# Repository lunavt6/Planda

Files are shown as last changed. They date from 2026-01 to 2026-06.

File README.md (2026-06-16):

# Planda
Een interactieve knuffelbeer die kinderen op een speelse en zelfstandige manier helpt bij het aanleren van dagelijkse taakjes.

🛠️ Built by ``Doren Vermaut`` & ``Luna Van Tittelboom`` & ``Bram Eeckhout``    
🔥 Supervised by ``prof. dr. Bas Baccarne``, ``Yannick Christiaens`` & ``Wouter Devriese``    
🌱 Grown at ``Ghent University`` 🏛️ ``Industrial Design Engineering`` ([project overview](https://github.com/basbaccarne/human-centered-design))       

*11/06/2026*   

## Samenvatting
Veel jonge ouders ervaren dagelijks stress tijdens het aanleren van routinetaken aan jonge kinderen. Taken zoals tanden poetsen, handen wassen, naar het toilet gaan of de boekentas voorbereiden vragen vaak voortdurende begeleiding, herhaling en controle. Dit zorgt voor frustratie bij zowel ouder als kind en vermindert de zelfstandigheid van het kind.

Om dit probleem te onderzoeken, doorliepen we een iteratief human-centered designproces met interviews, observaties, storyboards, benchmarking, ergonomische analyses en verschillende testwaves met prototypes. Tijdens het eerste semester lag de focus op een plannings- en routine-instrument voor de ochtendroutine. Uit feedback en gebruikerstesten bleek echter dat een puur planningsgericht systeem minder geschikt was binnen de hectiek van de ochtend. Daarom evolueerde het concept naar een interactieve begeleidende knuffelbeer die kinderen pedagogisch ondersteunt bij het aanleren van dagelijkse taakjes.

De uiteindelijke oplossing bestaat uit een zachte interactieve knuffelbeer met een scherm op de buik waarop visuele stappenplannen worden weergegeven. Via knoppen in de oortjes navigeert het kind doorheen de taakjes, ondersteund door licht- en geluidsfeedback. De beer begeleidt kinderen stap voor stap op een speelse, intuïtieve en zelfstandige manier, waardoor ouders minder voortdurend moeten tussenkomen en opvoedingsstress vermindert.

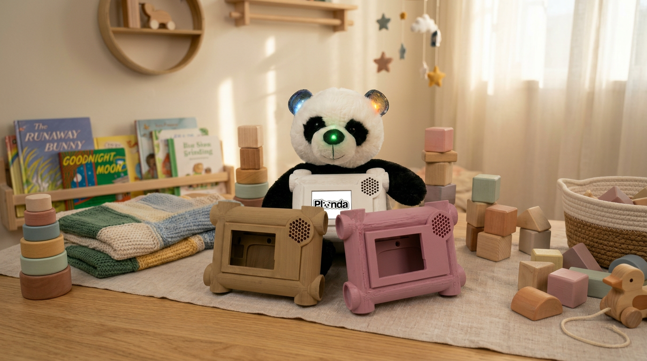
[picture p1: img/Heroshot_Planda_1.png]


## Introductie
Opvoeden brengt niet alleen plezier, maar ook veel stress met zich mee, zeker bij jonge ouders tijdens dagelijkse routines zoals tanden poetsen, handen wassen, aankleden of de boekentas voorbereiden. Veel kinderen hebben moeite om deze taken zelfstandig uit te voeren, waardoor ouders voortdurend moeten begeleiden, herhalen en controleren. Dit zorgt voor tijdsdruk, frustratie en gespannen interacties binnen het gezin.[^1] Onderzoek toont aan dat opvoedingsstress niet alleen een negatieve impact heeft op het welzijn van ouders, maar ook de zelfstandigheid en het zelfvertrouwen van kinderen kan beperken.

Het Planda Beer-project onderzoekt hoe een interactieve knuffelbeer kinderen pedagogisch kan begeleiden bij het aanleren van dagelijkse taakjes. In tegenstelling tot een klassiek planningsinstrument richt het concept zich op het stap voor stap ondersteunen van het kind via een speelse, fysieke en digitale interactie. De beer combineert een scherminterface met auditieve en visuele feedback, zoals geluid, LED-lichtjes en intuïtieve knopinteractie via de oortjes. Op deze manier wordt het kind zelfstandig begeleid zonder dat de ouder voortdurend actief moet tussenkomen.

Om tot deze oplossing te komen, werd een iteratief human-centered designproces doorlopen met interviews, observaties, storyboards, benchmarking, ergonomische analyses en meerdere prototypewaves. Hierbij werd onderzocht hoe kinderen reageren op licht, geluid, symbolen, feedback en fysieke interactie.

De boundary conditions van het project zijn duidelijk: het product moet veilig, zacht, robuust, intuïtief en kindvriendelijk zijn. Daarnaast mag de technologie geen extra stress creëren, maar net rust, autonomie en positieve interactie stimuleren.

## Inhoudstafel

1. [Methodologie](./docs/methodologie.md)
2. [Discovery](./docs/discovery.md)
3. [Definition](./docs/definition.md)
4. [Development 1](./docs/develop_1.md)
5. [Development 2](./docs/develop_2.md)
6. [Development 3](./docs/develop_3.md)
7. [Design Requirements](./docs/design_requirements.md)
8. [Bill of materials](./docs/bom.md)
9. [Conclusie](./docs/conclusie.md)

## Kritische reflectie
Het Planda‑project heeft over twee semesters heen een duidelijke en betekenisvolle evolutie doorgemaakt. Waar SEM1 vooral gericht was op het begrijpen van opvoedstress, kinderroutines en knuffelgedrag, lag de nadruk in SEM2 op het systematisch bouwen, testen en verfijnen van een interactief product dat zowel functioneel als emotioneel aansluit bij de leefwereld van jonge kinderen. Deze iteratieve aanpak heeft geleid tot een solide ontwerp, maar ook tot belangrijke inzichten over de beperkingen en uitdagingen van het project.

In SEM1 werd duidelijk dat een puur planningsgericht systeem onvoldoende aansluit bij de realiteit van gezinnen. De pivot naar een interactieve knuffelbeer was een cruciale stap: het toonde aan dat kinderen vooral reageren op fysieke, speelse en multisensorische prikkels. De Wizard‑of‑Oz‑testen en conceptual waves maakten zichtbaar hoe kinderen spontaan omgaan met licht, geluid en knuffelinteractie, en hoe belangrijk het is dat technologie zich aanpast aan hun natuurlijke gedrag in plaats van omgekeerd.

In SEM2 werd deze basis verder uitgediept. Develop 1 bracht de complexiteit van de functionele architectuur naar voren: het combineren van fysieke knoppen, visuele stappenplannen en auditieve feedback vraagt om een delicate balans tussen eenvoud en duidelijkheid. Develop 2 legde de nadruk op ergonomie en veiligheid. De antropometrische analyses en usabilitytests toonden aan dat kleine vormverschillen in de oortjes grote impact hebben op intuïtiviteit en comfort. Develop 3 richtte zich op UX en CMF, waarbij tactiliteit, materiaalkeuze en lichtdoorlaatbaarheid bepalend bleken voor de emotionele beleving van het product.

Toch blijven er kritische kanttekeningen. De steekproef blijft beperkt, waardoor sommige inzichten (zoals kleurassociaties of voorkeur voor oorknoppen) niet universeel gegarandeerd zijn. Daarnaast blijft de context van testen relatief gecontroleerd; echte ochtendstress is moeilijk te simuleren. Dit betekent dat gedrag dat in testsituaties voorspelbaar lijkt, in een chaotische ochtendroutine anders kan uitpakken.

Ook de vraag naar langdurige motivatie blijft open: blijven kinderen reageren op licht‑ en geluidsfeedback, of treedt gewenning op na enkele weken? Dit is essentieel, omdat het succes van Planda Beer afhangt van duurzame betrokkenheid. Tot slot introduceert het afneembare scherm praktische uitdagingen: hoewel ouders het waarderen, vormt het een extra handeling die in drukke routines snel vergeten kan worden. Dit vraagt om verdere vereenvoudiging of automatisering.

Daarnaast toont het project aan dat elke ontwerpkeuze een spanningsveld creëert: tussen knuffelbaarheid en functionaliteit, tussen autonomie en veiligheid, tussen eenvoud en veelzijdigheid. Het vinden van de juiste balans blijft een voortdurende uitdaging.

Ondanks deze beperkingen heeft het project een sterke methodologische basis gelegd. De combinatie van kwalitatieve observaties, iteratieve prototyping en empirische validatie heeft geleid tot een onderbouwd ontwerp dat rekening houdt met zowel kind als ouder. De kritische reflectie toont vooral dat Planda Beer potentieel heeft, maar dat verdere testen, grotere steekproeven en langdurige evaluaties noodzakelijk zijn om een product te creëren dat écht werkt in diverse gezinsomgevingen.

## Noot inzake het gebruik van AI
In dit project werd AI enkel als ondersteunend hulpmiddel gebruikt. We zetten AI in om enkele eigen schetsen netter te visualiseren, renders te maken, teksten vlotter te formuleren, en tabellen of schema’s overzichtelijk op te maken zodat ze makkelijk in Visual Studio Code konden worden geïmporteerd. Alle concepten, ontwerpen, analyses en beslissingen zijn volledig door het projectteam zelf ontwikkeld; AI werd uitsluitend ingezet voor vormgeving en taalondersteuning.

## Bijlagen
### Discovery
* Benchmarkonderzoek (N=14)
  * [Protocol](https://drive.google.com/file/d/1VPV1awJDa64VDqinm8LVtdigFpOs-lXI/view?usp=sharing)
  * [Rapport](https://drive.google.com/file/d/1ek-WHoF4-XrpG6pTKncxjXwMrDPfr108/view?usp=sharing)
* Interviews (N=3)
  * [Protocol](https://drive.google.com/file/d/1N_GjyhnOHkRdai5fe6EW2gFWemPGeeNa/view?usp=sharing)
  * [Rapport](https://drive.google.com/file/d/19u9PNdlWeaDVB6IC4Rpc8PkJ9rHKdnLq/view?usp=sharing)
    
### Definition
* User testing wave 1 (N=4)
  * [Protocol](https://drive.google.com/file/d/130vRvOUCvCWISH5MEXmbPGNB_Uw2ju9m/view?usp=drive_link)
  * [Rapport](https://drive.google.com/file/d/1wbh-eud349pPwJQK2OwwAVadwWI7WrDZ/view?usp=drive_link)
* User testing wave 2 (N=6)
  * [Protocol](https://drive.google.com/file/d/1jO9U5P_zEwsMB1liQGqoZsyC6XyTrukl/view?usp=drive_link)
  * [Rapport](https://drive.google.com/file/d/1y09vUGmh9ruJW8-vAtFctbpJqeW_Oqac/view?usp=drive_link)

### Development 1
* Literatuuronderzoek (N=11)
  * [Protocol](https://drive.google.com/file/d/1JkM7xMZF1cOWVq1P75I5-xc_WWrdSNv_/view?usp=sharing)
  * [Rapport](https://drive.google.com/file/d/1lqU_Gb7P2KewI6b2YRbHUHMy500uVC_5/view?usp=sharing)
* User testing (N=3)
  * [Protocol](https://drive.google.com/file/d/15MI33pND1JuIGdH_J8u2If2VXpHv9gB-/view?usp=sharing)
  * [Rapport](https://drive.google.com/file/d/1iAICvbYoYDdQVMLRW9RndhLdhfBj4c1h/view?usp=sharing)

### Development 2
* Antropometrie onderzoek
  * [Rapport](https://drive.google.com/file/d/1W2tFgDZaNar4k2NG-botPuARzz3v3zZD/view?usp=sharing)
* User testing (N=1)
  * [Protocol](https://drive.google.com/file/d/18UV0sOgIwRFaU0k2yumadGYeaR9zQ-xK/view?usp=sharing)
  * [Rapport](https://drive.google.com/file/d/10HXQ8sNEB7mYRsCe3yflU_DUqUeTnOM8/view?usp=sharing)

### Development 3
* User testing (N = 3)
  * [Protocol](https://drive.google.com/file/d/1nMEvOunnXXP05v1LXsKzn6qRlS9hDP_Y/view?usp=sharing)
  * [Rapport](https://drive.google.com/file/d/1Gyd1z_1kM8eNMYuMG_D5NSGw8vEMbcCc/view?usp=sharing)
  * [PowerPoint omhulsel](https://drive.google.com/file/d/1jtBIYcoHiLNUWgVYdP9SYzcHUyG76-D9/view?usp=sharing)
  * [PowerPoint oortjes](https://drive.google.com/file/d/1XNqXtDPErmhQJFLdnw9bNmKRSQDc-u7y/view?usp=sharing)

## Licentie  

This repository contains both software and design materials created as part of an industrial design energineering project at Ghent University.

- **Software and code:** [MIT License](./LICENSE-MIT)  
- **Design, documentation, CAD, and media:** [CC BY 4.0 License](./LICENSE)
  
You are free to reuse and build upon this work, both commercially and non-commercially, as long as proper attribution is given to the original authors.

## Bronnen
[^1]: Persoonlijk interview met Sofie, 18 oktober 2025; persoonlijk interview met Ludovic, 19 oktober 2025; persoonlijk interview met Kaat, 19 oktober 2025.

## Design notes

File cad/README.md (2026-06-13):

Voor ons project hebben we de oortjes van de bestaande beer herontworpen zodat ze kunnen functioneren als drukknoppen.

Hiervoor hebben we de oortjes ontworpen in CAD en vervolgens een mal ontwikkeld waarmee de oortjes gerealiseerd konden worden door silicone in de mal te gieten.

Om de oortjes stevig aan de beer te bevestigen, hebben we daarnaast een bevestigingsboog ontworpen. De oortjes worden op deze boog vastgelijmd, waarna de volledige constructie onder de vacht van de beer wordt geplaatst.

**Bevestegingsboog**

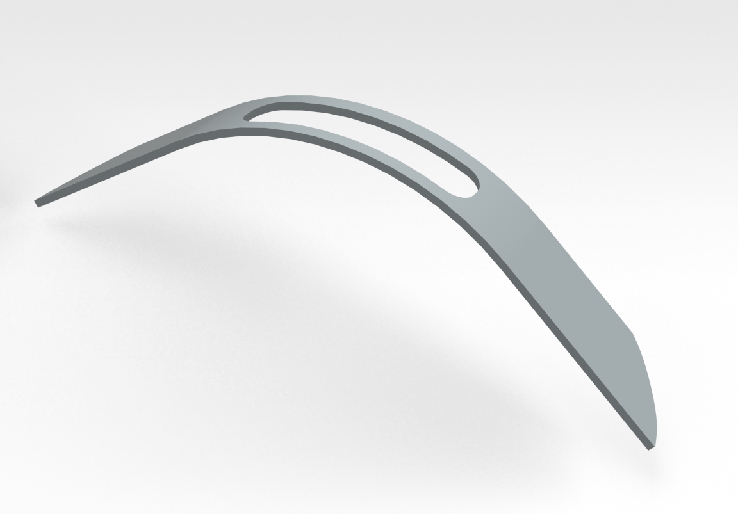
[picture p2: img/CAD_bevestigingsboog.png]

CAD-bestand: [bevestigingsboog.prt](./bevestegingsboog.prt)

**Mal oortje**

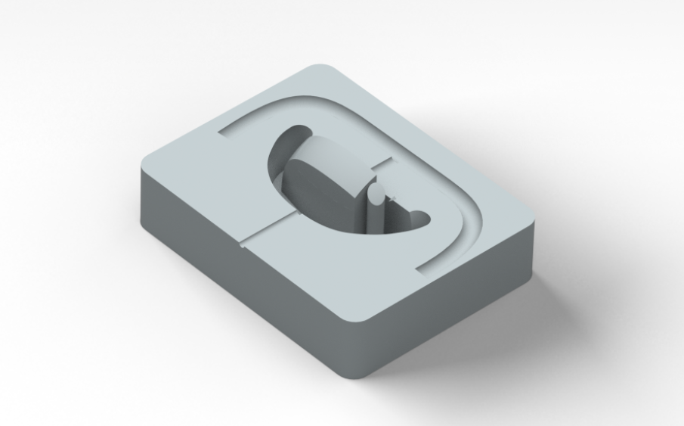
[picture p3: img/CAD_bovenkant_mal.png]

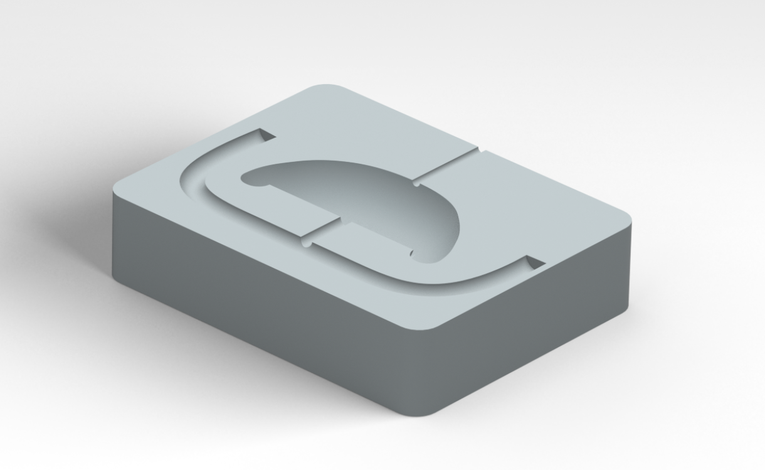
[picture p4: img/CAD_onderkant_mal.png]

CAD-bestand: [mal.prt](./mal.prt)

**Oortje**

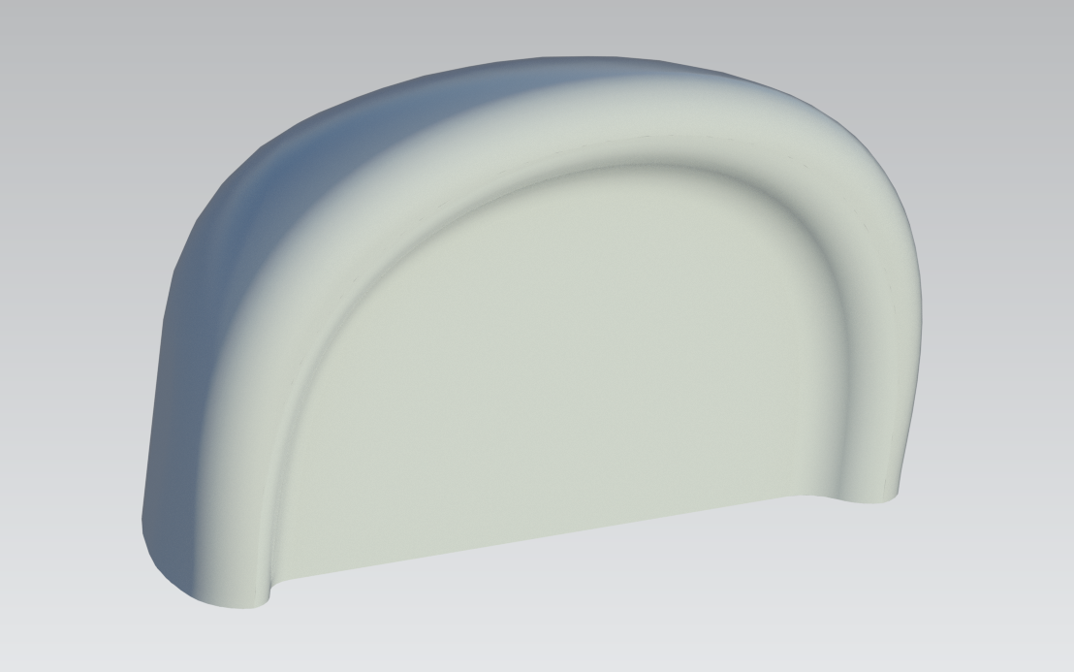
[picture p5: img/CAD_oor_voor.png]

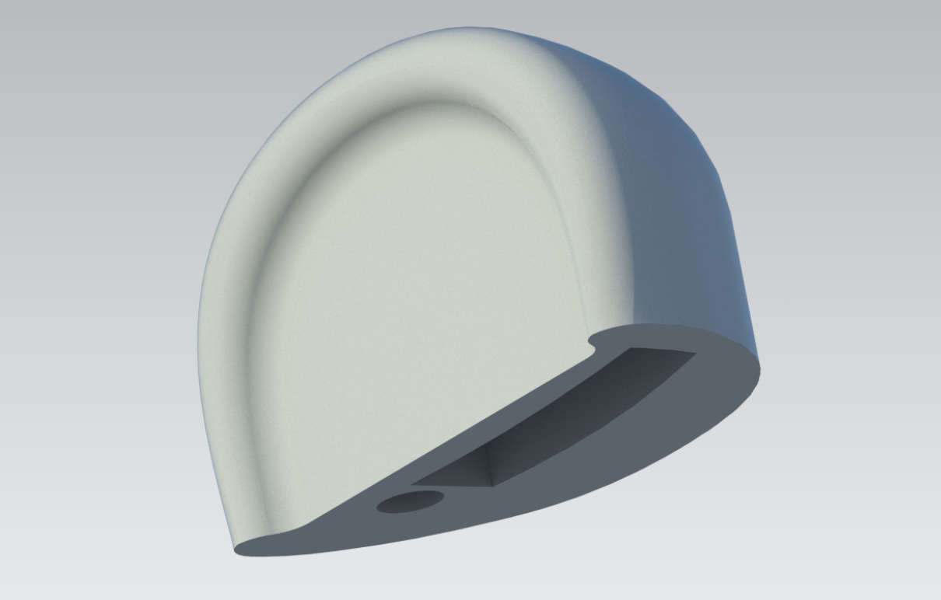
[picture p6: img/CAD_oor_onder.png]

CAD-bestand: [oortjes.prt](./oortjes%20eerste%20versie%20-%20kopie%20-%20kopie.prt)

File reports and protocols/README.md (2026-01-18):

Add PDF versions of your protocols and reports here.   
   
- ❗Make sure this data is pseudonomized (give an alias to your respondent)    
- ❗Don't share personal information here.   
- ❗For informed consents and other documents that contain personal information: Add links to a OndeDrive folder and only give access to teachers.

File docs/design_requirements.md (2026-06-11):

## Overzicht van Design Requirements
|| **Status** || ❌ niet voldaan || ⚠️ gedeeltelijk voldaan || ✅ voldaan || 💭 theoretisch voldaan ||
|ID|Design Requirement|Source|Status|
|:---|:---|:---|:---:|
|**Functionaliteit & Ondersteuning**|
|1.1|Het product geeft taken duidelijk en motiverend weer.|[Discovery](discovery.md)|✅|
|1.2|Het product ondersteunt de gebruiker tijdens de activiteit.|[Discovery](discovery.md)|✅|
|1.3|Het product is personaliseerbaar.|[Discovery](discovery.md)|✅|
|1.4|Het product geeft visuele en auditive feedback aan de gebruiker.|[Definition: Wave 2](definition.md) & [Develop 3](develop_3.md)|✅|
|1.5|Het scherm is losneembaar van het hoofdproduct.|[Definition: Wave 1](definition.md)|✅|
|1.6|De beer biedt aangepaste begeleiding met minstens twee niveaus: een beginnersmodus met gedetailleerde stappen en een gevorderde modus met kortere instructies.|[Develop 1](develop_1.md)|❌|
|1.7|Elke stap communiceert één duidelijke actie en is visueel eenvoudig en herkenbaar voor jonge kinderen.|[Develop 1](develop_1.md)|✅|
|1.8|De beer leest elke stap automatisch voor via een ingebouwde speaker.|[Develop 1](develop_1.md)|❌|
|**Interactie & Bediening**|
|2.1|Het product is intuïtief en eenvoudig te gebruiken.|[Discovery](discovery.md)|✅|
|2.2|Het product beschikt over fysieke knoppen.|[Definition: Wave 1](definition.md)|✅|
|2.3|De knoppen zijn ergonomische en toegankelijke gepositioneerd voor de doelgroep.|[Definition: Wave 1](definition.md)|✅|
|2.4|De knoppen zijn op een logische manier t.o.v. elkaar gepositioneerd. |[Definition: Wave 2](definition.md)|✅|
|2.5|Lichtsignalen geven aan welke knop er moet ingeduwd worden.|[Definition: Wave 2](definition.md)|✅|
|2.6|De kleuren van de lichtsignalen zorgen voor een duidelijke interpretatie.|[Definition: Wave 2](definition.md)|❌|
|2.7|Het product gebruikt geluid om de aandacht van het kind te trekken.|[Definition: Wave 2](definition.md)|✅|
|2.8|Het  oor heeft een grootte die comfortabel en gemakkelijk te gebruiken is voor een kind.|[Develop 2](develop_2.md)|✅|
|2.9|Het oor heeft een voldoende grote contactoppervlak voor een stabiele grip.|[Develop 2](develop_2.md)|✅|
|**Vormgeving & Beleving**|
|3.1|Het product heeft een speels karakter door het gebruik van opvallende kleuren en herkenbare visuele kenmerken.|[Discovery](discovery.md) & [Develop 3](develop_3.md)|✅|
|3.2|Het product behoudt het knuffelaspect.|[Definition: Wave 1](definition.md)|✅|
|3.3|Het product heeft een ergonomische vorm die makkelijk vast te houden is door de doelgroep.|[Definition: Wave 1](definition.md)|✅|
|3.4|Het product bevat onderdelen die gereinigd kunnen worden.|[Definition: Wave 1](definition.md)|💭|
|3.5|De oortjes hebben een zachte en elastische interface.|[Develop 3](develop_3.md)|✅|
|3.6|Het omhulsel voelt glad aan.|[Develop 3](develop_3.md)|✅|
|3.7|Het product is beschikbaar in verschillende kleurvarianten.|[Develop 3](develop_3.md)|❌|
|**Vormgeving app**|
|4.1|De app is eenvoudig en overzichtelijk, zodat ouders snel taken kunnen instellen of aanpassen.|[Develop 1](develop_1.md)|✅|
|4.2|Ouders kunnen routines volledig aanpassen door taken toe te voegen, te verwijderen of de volgorde te wijzigen.|[Develop 1](develop_1.md)|✅|
|4.3|De app bevat standaardtaken.|[Develop 1](develop_1.md)|✅|
|4.4|Ouders kunnen eerder ingestelde routines opslaan en opnieuw gebruiken.|[Develop 1](develop_1.md)|✅|
|4.5|De app ondersteunt meerdere kinderaccounts, zodat elk kind een eigen profiel en voortgang heeft.|[Develop 1](develop_1.md)|✅|
|4.6|Beide ouders kunnen via hun eigen smartphone toegang krijgen tot de beer en voortgang bekijken.|[Develop 1](develop_1.md)|✅|
|4.7|Voortgang van kinderen wordt visueel weergegeven.|[Develop 1](develop_1.md)|✅|
|4.8|De app toont voortgang over langere tijd.|[Develop 1](develop_1.md)|✅|
|4.9|Ouders ontvangen herinneringen om oefenmomenten niet te vergeten.|[Develop 1](develop_1.md)|✅|
|4.10|De app geeft praktische tips voor het oefenen van vaardigheden met het kind.|[Develop 1](develop_1.md)|✅|
|4.11|De verbinding tussen de app en de beer is duidelijk zichtbaar, inclusief correcte overdracht van routines.|[Develop 1](develop_1.md)|✅|

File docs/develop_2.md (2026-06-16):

## Development 2

### Doelstellingen
Het hoofddoel van deze fase is het ergonomisch maken van het product en wordt de opstelling verbeterd.

---

### Ergonomie

#### Materiaal & methoden
Om de beer op ergonomisch vlak te kunnen evalueren, werd hij geanalyseerd op zijn verschillende componenten. Al snel werd duidelijk dat enkel de oren (die dienen als knoppen) een ergonomisch aspect bevatten. Deze knoppen moeten namelijk gemakkelijk inknijpbaar zijn en goed in de hand liggen van kinderen.

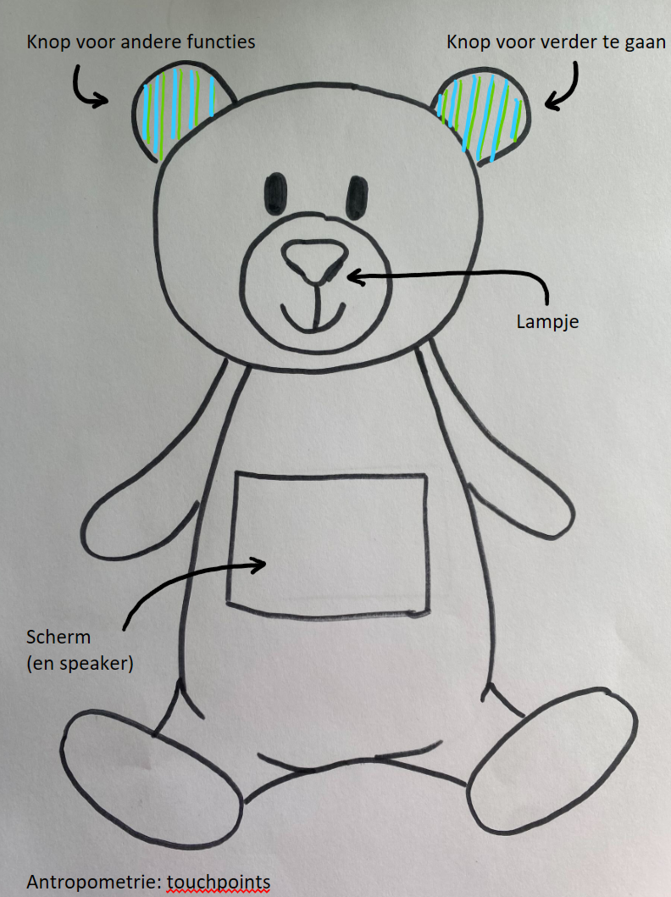
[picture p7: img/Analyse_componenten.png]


Er werd een antropometrische analyse uitgevoerd waarbij onderzocht werd op welke verschillende manieren kinderen kunnen knijpen in een voorwerp en welke krachten zij daarbij uitoefenen. De nodige informatie werd gehaald uit een academisch verslag, gevonden via Google Scholar, aangezien bestaande antropometrische databanken niet veel specifieke gegevens bevatten over kinderhanden. In dit verslag werden verschillende tabellen met krachtwaarden geraadpleegd. Hieruit werden enkel de resultaten voor 5 – 6 jarigen gebruikt, aangezien deze de enige zijn die zich in de doelgroep bevinden. Daarnaast werd het principe van “design for the small” toegepast, zodat het ontwerp ook geschikt blijft voor grotere handen en sterkere krachten.

Deze analyse maakte het duidelijk wat er verder onderzocht moest worden in de gebruikerstesten. Tijdens de testen werd gekeken naar de handzetting van de kinderen op de oren en naar welke oorgrootte zij het meest gebruiksvriendelijk vinden. Het prototype hiervoor is te zien in onderstaande afbeelding.

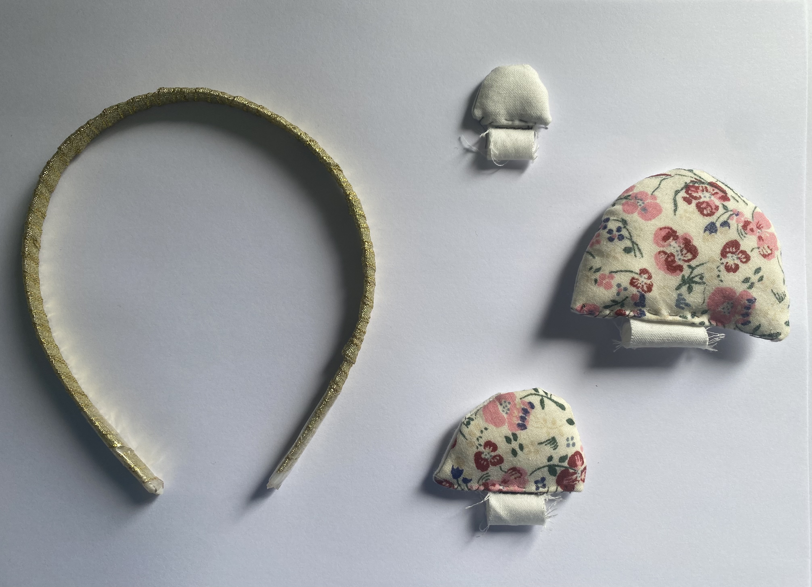
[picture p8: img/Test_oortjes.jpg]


Het protocol van de gebruikerstesten is [hier](https://drive.google.com/file/d/18UV0sOgIwRFaU0k2yumadGYeaR9zQ-xK/view?usp=sharing) te vinden.

#### Resultaten

##### Antropometrisch onderzoek
Uit de antropometrische analyse is gebleken dat er toch een groot verschil is in de uitgeoefende krachten, afhankelijk van de manier van knijpen. Dit wordt weergegeven in onderstaande tabel, waarin telkens de minimale krachtwaarden zijn opgenomen. 

|Soort kracht|Minimum kracht (in N)|Afbeelding|
|---|---|---|
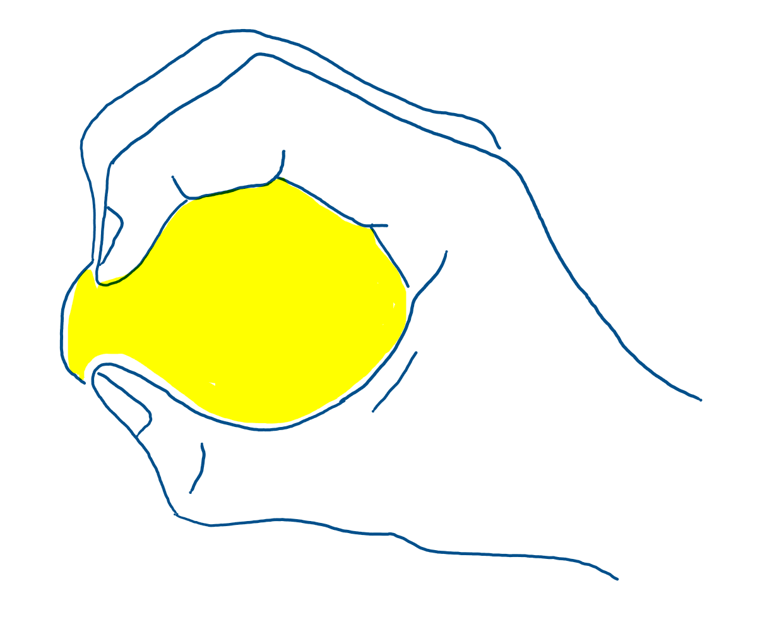
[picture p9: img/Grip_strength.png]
|Grip strength|75.62||
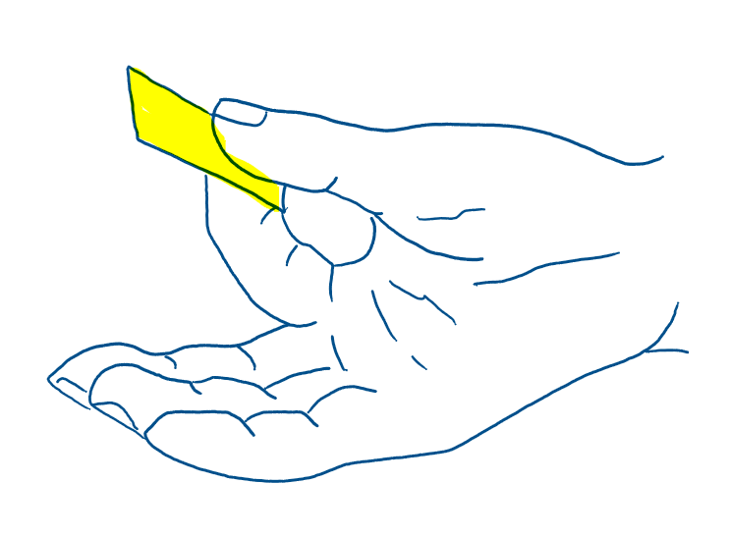
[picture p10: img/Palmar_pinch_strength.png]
|Palmar pinch strength|13.79||
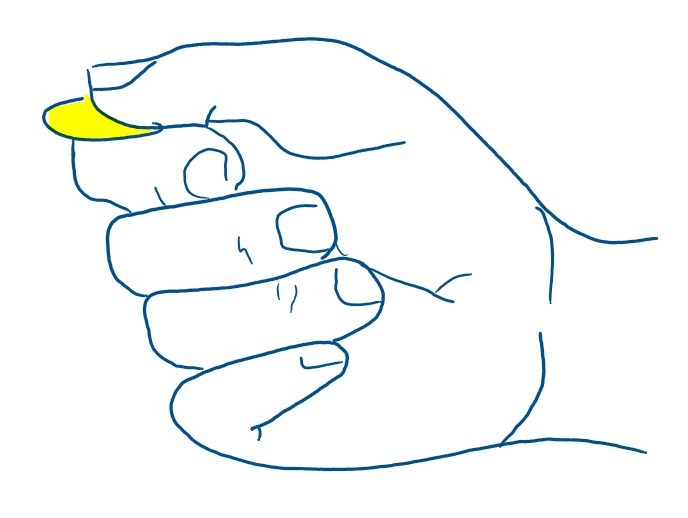
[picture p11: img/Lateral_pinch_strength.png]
|Lateral pinch strength|8.01||

Uit deze tabel blijkt dat het belangrijk is om rekening te houden met de manier waarop kinderen de knoppen bedienen. De kracht die wordt uitgeoefend met de vingers verschilt namelijk sterk van de kracht die met de volledige hand wordt gebruikt. Het is daarom belangrijk om te weten te komen hoe kinderen de knoppen spontaan indrukken. 

Voor het bepalen van de grootte van de knoppen werd er geen bruikbare data gevonden. Daarom worden er verschillende quick-and-dirty prototypes gemaakt met variërende knopgroottes, zodat getest kan worden welke afmetingen het meest comfortabel zijn voor de kinderen.

De analyse van het antropometrisch onderzoek is [hier](https://drive.google.com/file/d/1W2tFgDZaNar4k2NG-botPuARzz3v3zZD/view?usp=sharing) te vinden.

##### Testinterviews
Er wordt gevraagd aan het kind om in de oor van de beer te knijpen zoals te zien is in onderstaande afbeelding en dit wordt dan herhaald voor de verschillende groottes.

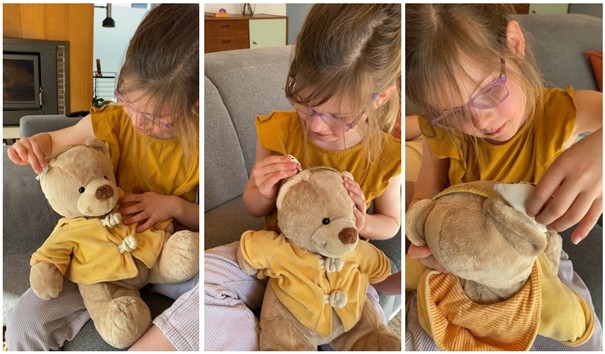
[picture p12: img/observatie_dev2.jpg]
observatie


De positie van de hand werd per oorgrootte vijf keer geobserveerd. Deze observaties worden samengevat in onderstaande tabel.

| | 1 | 2 | 3 | 4 | 5 |
|---|---|---|---|---|---|
| **Kleinste** | Duim + 2 vingers | Duim + 2 vingers | Duim + 2 vingers | Duim + 2 vingers | Duim + 2 vingers |
| **Middelste**  | Duim + 1 vinger  | Duim + 3 vingers | Duim + 2 vingers | Duim + 3 vingers | Volledig hand |
| **Grootste** | Duim + 3 vingers | Duim + zijkant vinger | Duim + 3 vingers | Duim + 3 vingers | Duim + 3 vingers |

Uit de resultaten kan worden afgeleid dat de knop meestal wordt bediend met de duim in combinatie met één of meerdere vingers. Deze manier van vasthouden lijkt de voorkeur te hebben. Daarnaast is er een duidelijk verschil zichtbaar afhankelijk van de grootte van het oor. Bij het kleinste oor wordt hele tijd gebruikgemaakt van de duim samen met twee vingers. Bij het middelste oor varieert de handpositie sterker, van de duim met één vinger tot het gebruik van het volledige hand. Bij het grootste oor wordt voornamelijk de duim samen met drie vingers gebruikt.

Hieruit kan worden afgeleid dat de grootte van het oor invloed heeft op hoe het kindje de knop vastneemt en gebruikt. Grotere oren zorgen ervoor dat er meer vingers worden gebruikt, terwijl kleinere oren leiden tot een beperktere maar meer vaste handpositie.

Tijdens de evaluatie achteraf gaf het kindje aan dat het middelste oor het meest comfortabel en het gemakkelijkst in gebruik was. Dit komt overeen met de grotere variatie in handposities, wat erop kan wijzen dat deze grootte meer flexibiliteit biedt. 

Het report van de gebruikerstesten is [hier](https://drive.google.com/file/d/10HXQ8sNEB7mYRsCe3yflU_DUqUeTnOM8/view?usp=sharing) te vinden.

---

### Feedback
#### Visueel
Het is belangrijk dat het kind duidelijk begrijpt welke taak uitgevoerd moet worden en op welke manier deze uitgevoerd kan worden. Om de taakjes visueel weer te geven, worden GIF-animaties gebruikt die afgespeeld worden op het TFT-display.

Binnen het systeem wordt een onderscheid gemaakt tussen taakjes en hints. De taakjes tonen enkel de actie die uitgevoerd moet worden. Op deze manier krijgt het kind informatie over wat er moet gebeuren, zonder extra uitleg over de uitvoering. De hints leggen daarentegen meer nadruk op hoe de taak uitgevoerd moet worden en tonen daarom een meer gedetailleerde weergave van de actie.

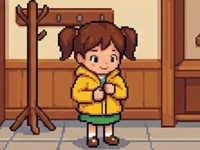
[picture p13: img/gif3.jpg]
    

Omdat de GIF-bestanden momenteel opgeslagen worden in het interne geheugen van de ESP32, is de beschikbare opslagruimte beperkt. Hierdoor moeten de animaties relatief eenvoudig blijven en kunnen ze minder gedetailleerde beelden bevatten. Vooral de GIF-animaties die de uitvoering van een taak uitleggen, zullen hierdoor beperkt zijn in lengte en detail.

Wanneer in een toekomstige versie gebruikgemaakt wordt van de SD-kaartlezer die geïntegreerd is in het TFT-display, kan de opslagcapaciteit aanzienlijk uitgebreid worden. Hierdoor wordt het mogelijk om langere en meer gedetailleerde GIF-animaties te gebruiken.

#### Audio
Naast visuele feedback wordt ook audiofeedback voorzien. Elk taakje wordt eerst door een stem uitgesproken, zodat het kind de opdracht correct begrijpt en de GIF-animatie niet verkeerd interpreteert. Voor de hints wordt eveneens een gesproken uitleg voorzien die beschrijft hoe de taak uitgevoerd moet worden, gevolgd door een ondersteunend muziekje.

Wanneer een taak succesvol voltooid is, krijgt het kind positieve bevestiging via een applausgeluid. Op deze manier wordt de interactie niet enkel informatief, maar ook motiverend gemaakt.

---

### Conclusies & implicaties

#### Ergonomie
Uit het ergonomisch onderzoek en de gebruikerstesten blijkt dat de grootte en vorm van het oor een belangrijke invloed hebben op het gebruiksgemak van de beer. De resultaten geven inzicht in hoe kinderen de oren vastnemen en bedienen, en welke eigenschappen bijdragen aan een comfortabele en betrouwbare interactie.

In onderstaande tabel worden de conclusies weergegeven met de bijhorende reden of onderbouwing waarop de design requirements gebaseerd zijn. 

| Conclusie | Reden |
|---|---|
| Het oor moet een grootte hebben die comfortabel en gemakkelijk te gebruiken is voor kinderen. | Tijdens de gebruikerstesten gaf het kind aan dat het middelste oor het meest comfortabel en het gemakkelijkst in gebruik was. De variatie in handposities wijst erop dat deze grootte voldoende flexibiliteit biedt voor verschillende manieren van vasthouden. |
| Het oor moet een voldoende groot contactoppervlak hebben voor een stabiele grip. | Observaties tonen aan dat kinderen de knop voornamelijk bedienen met de duim en één of meerdere vingers. Een compacter en breder oor biedt een groter contactoppervlak, waardoor kinderen gemakkelijker druk uitoefenen op de juiste plaats en de knop betrouwbaarder activeren. |

> [!IMPORTANT]
> **Design Requirements**
>- 2.8 Het  oor heeft een grootte die comfortabel en gemakkelijk te gebruiken is voor een kind.
>- 2.9 Het oor heeft een voldoende grote contactoppervlak voor een stabiele grip.

#### Aanpassingen oortjes
Tijdens het iteratief ontwerpproces werd de vorm van de oortjes verder verfijnd op basis van de design requirements. Het oorspronkelijke ontwerp bestond uit een langwerpig oortje, maar dit bleek minder geschikt. Enerzijds was deze vorm te lang voor de voorziene mal, en anderzijds zorgde dit voor een minder optimale interactie.

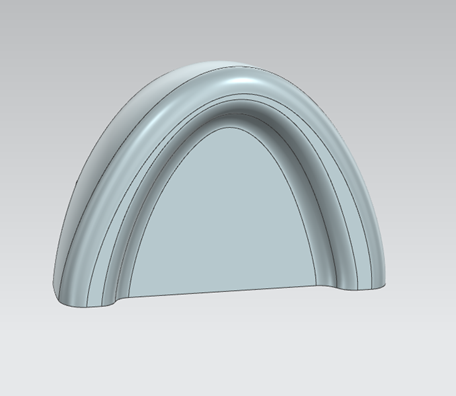
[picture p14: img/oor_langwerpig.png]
langwerpig
 

Een compacter en breder oortje bood een duidelijk betere ergonomische ervaring. Doordat de breedte meer in verhouding staat tot de grootte van de beer, ontstaat er een groter contactoppervlak. Dit verhoogt de kans dat kinderen effectief druk uitoefenen op de juiste plaats en dus succesvol de knop activeren. Bij het langwerpige ontwerp bestond namelijk het risico dat kinderen op de zijkant drukten zonder de interne knop in te drukken. Dit probleem wordt met de huidige vorm vermeden.

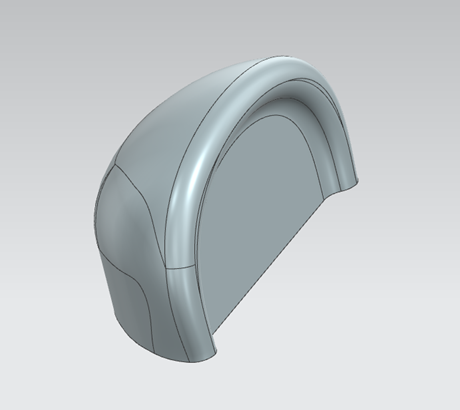
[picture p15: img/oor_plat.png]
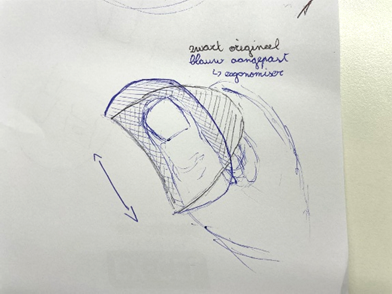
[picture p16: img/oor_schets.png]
 

#### Opstelling
De volgende stappen in het project zijn:
1.	Testen van oren + scherm
2.	Een manier bedenken om het scherm draagbaar te maken door bv. batterijen te gebruiken.

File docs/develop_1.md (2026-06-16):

## Development 1

### Doelstellingen
Het hoofddoel van de eerste develop-fase was het verkennen van de mogelijkheden voor het product, met de volgende deeldoelen: inzicht krijgen in de ontwikkeling van kinderen, onderzoeken hoe zij interageren met de interface van de beer, mogelijke ontwerpen van de bijbehorende app verkennen, en bepalen hoe het product gerealiseerd kan worden.

---

### Materiaal & methoden
Voordat de interviews en literatuuronderzoek konden starten, werd eerst een functionele analyse uitgevoerd. In dit proces werd een verbeterde en meer gedetailleerde versie van het storyboard gemaakt om te onderzoeken wat de verschillende stappen zijn die met en zonder het product doorlopen worden. 

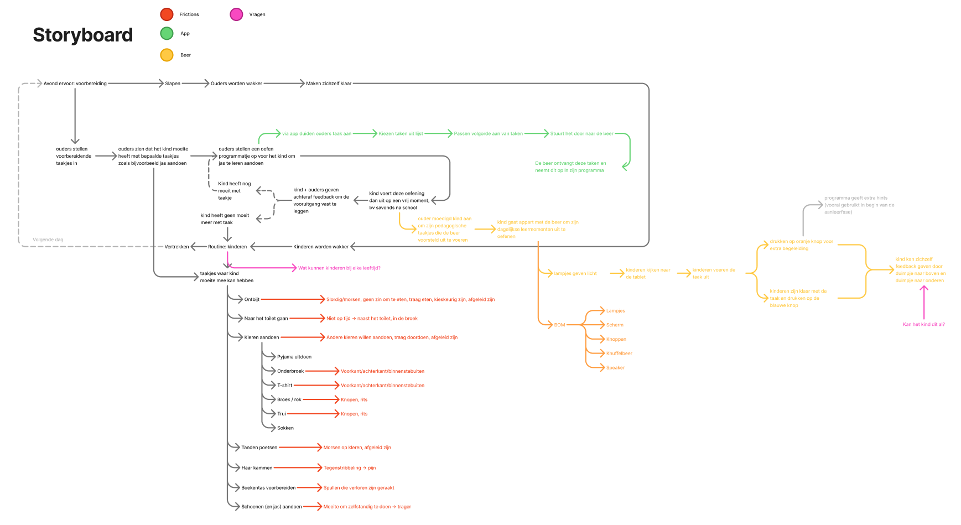
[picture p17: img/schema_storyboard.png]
schema


In onderstaand storyboard wordt er een ideale ochtendroutine voorgesteld.

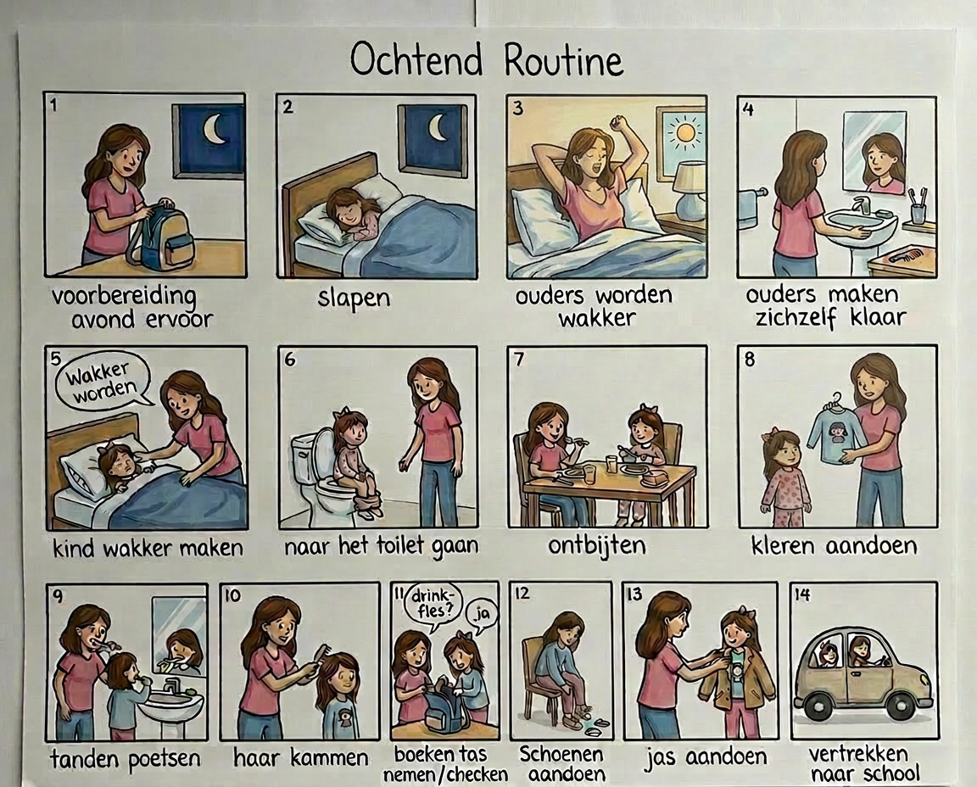
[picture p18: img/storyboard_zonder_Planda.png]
storyboard_zonder_Planda


Aangezien de ochtend niet altijd soepel verloopt, wordt hier ook een worst-case variant van gemaakt.

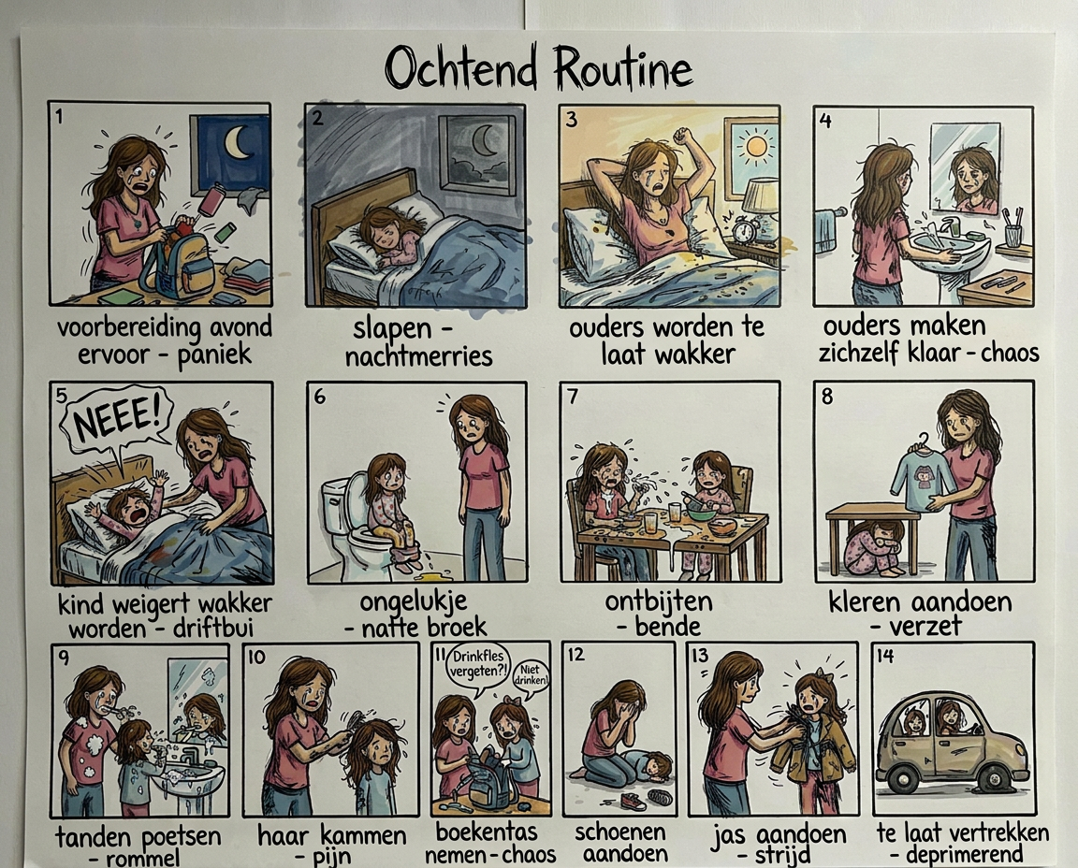
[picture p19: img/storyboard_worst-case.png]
storyboard_worst-case


In onderstaand storyboard is dan te zien waar Planda kan worden ingezet.

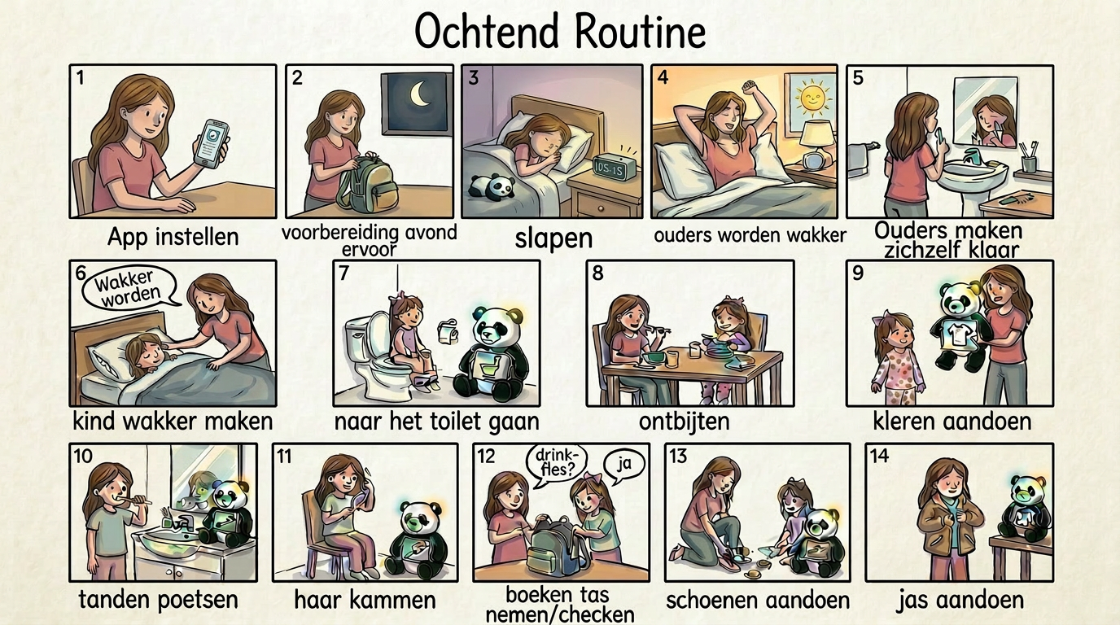
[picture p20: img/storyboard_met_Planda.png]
storyboard_met_Planda


Daarna werd er een literatuuronderzoek uitgevoerd om de ontwikkeling van een kind beter te begrijpen. Hierbij werd onderzoek gedaan naar de verschillende domeinen : motorisch, cognitief, sociaal-emotioneel en taalontwikkeling. Informatie kwam uit openbare bronnen, zoals websites, blogs en academisch onderzoek. Vervolgens werd de informatie vergeleken, zodanig dat er een tijdlijn van kon gemaakt worden. 

Het protocol voor het literatuuronderzoek is [hier](https://drive.google.com/file/d/1JkM7xMZF1cOWVq1P75I5-xc_WWrdSNv_/view?usp=sharing) te vinden.

Tijdens de testen van de interactieve beer werd een Wizard of Oz-opstelling gebruikt. Hierbij fungeerde een fysieke knuffelbeer als tastbare interface, terwijl een smartphone op de buik het Figma-prototype toonde. Via een Bluetooth-muis werden de schermen op afstand bestuurd, zodat de volledige interactiestroom getest kon worden zonder dat de echte hardware en software al ontwikkeld waren. De focus van de test lag vooral op het gedrag, begrip en de motivatie van kinderen tijdens dagelijkse zelfzorgtaken zoals handen wassen.

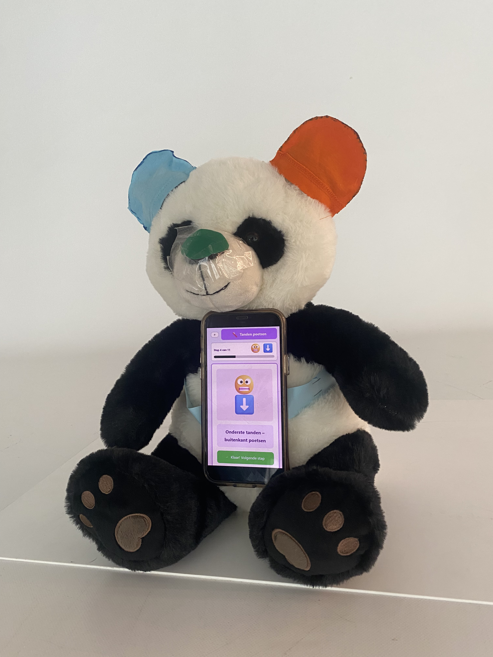
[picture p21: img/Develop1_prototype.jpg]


Daarna werden de noden voor de app onderzocht. Eerst werd aan de geïnterviewden gevraagd wat zij van de app verwachtten. Vervolgens werd een eerste versie van de app getoond en werd gevraagd welke functies of aanpassingen volgens hen nog ontbraken. 

De eerste versie van de app is hier te vinden: [Planda App](https://www.figma.com/make/4M9PoDPEkh4jKd4S3BSqR9/Planda-App-V1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)

Het protocol voor de interview-testen is [hier](https://drive.google.com/file/d/15MI33pND1JuIGdH_J8u2If2VXpHv9gB-/view?usp=sharing) te vinden.

---

### Resultaten
#### Literatuuronderzoek 
Uit dit onderzoek wordt duidelijk waarom gekozen werd voor de doelgroep van 2 tot 6 jaar. In deze periode maken kinderen een sterke ontwikkeling door. Ze zijn nieuwsgierig naar de wereld om zich heen, leren steeds zelfstandiger te worden en bouwen hun sociale vaardigheden verder uit. Tegelijk zetten ze hun eerste stappen in het kleuteronderwijs. Omdat in deze jaren de basis wordt gelegd voor hun verdere ontwikkeling, is het belangrijk om deze leeftijdsgroep goed in kaart te brengen.

Bijgevolg zijn volgende tijdlijnen ontstaan waarbij telkens één domein wordt bekeken.
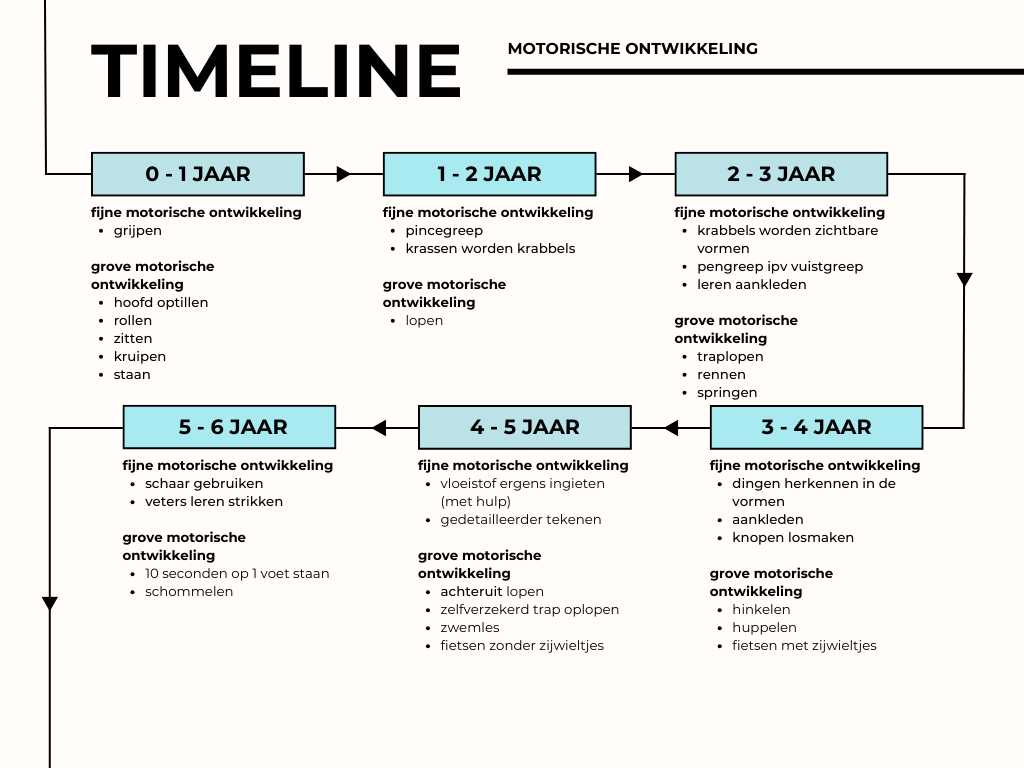
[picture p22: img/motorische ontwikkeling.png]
Motorische

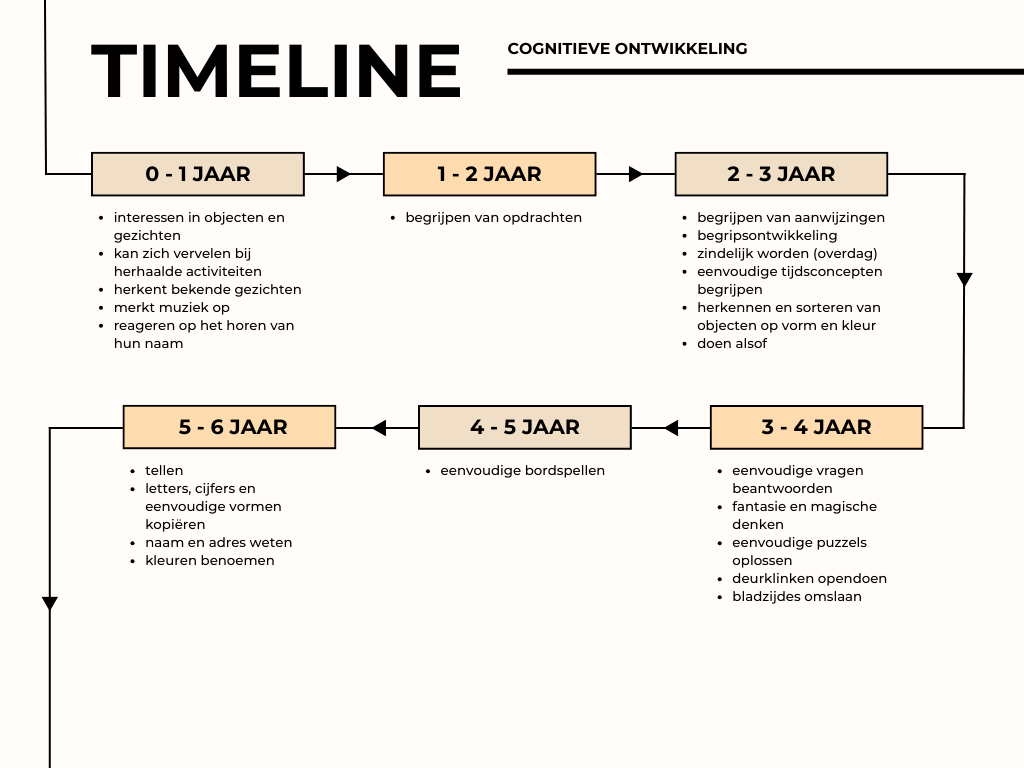
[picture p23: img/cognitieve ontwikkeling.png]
Cognitieve

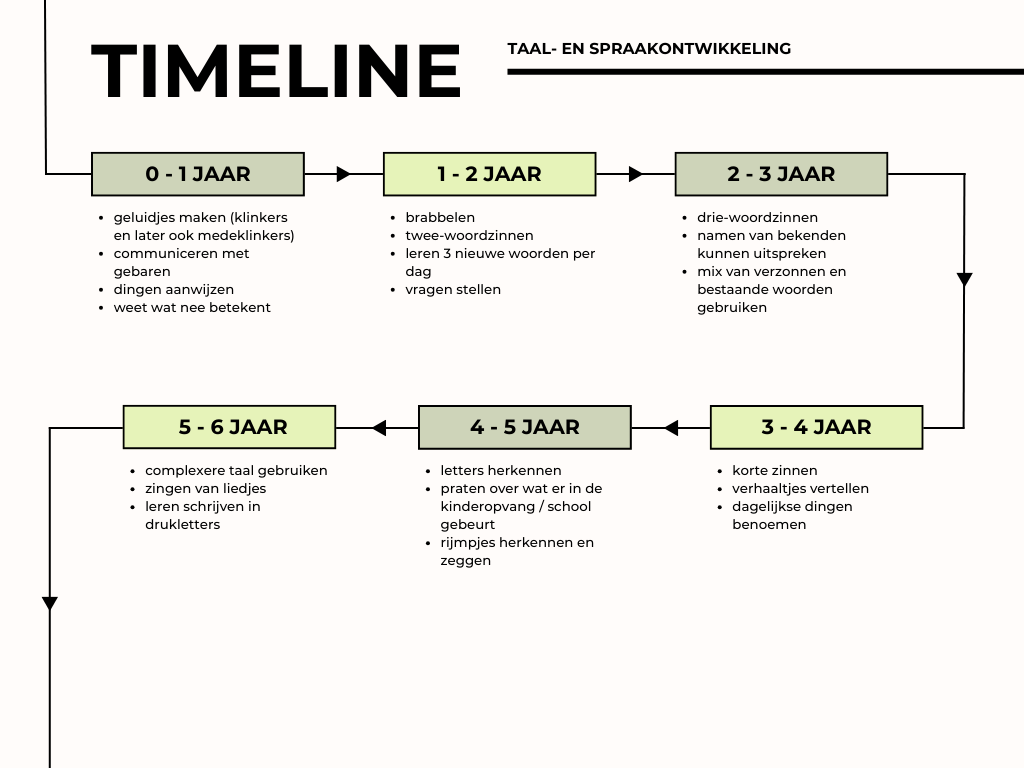
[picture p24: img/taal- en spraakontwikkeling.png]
Taal

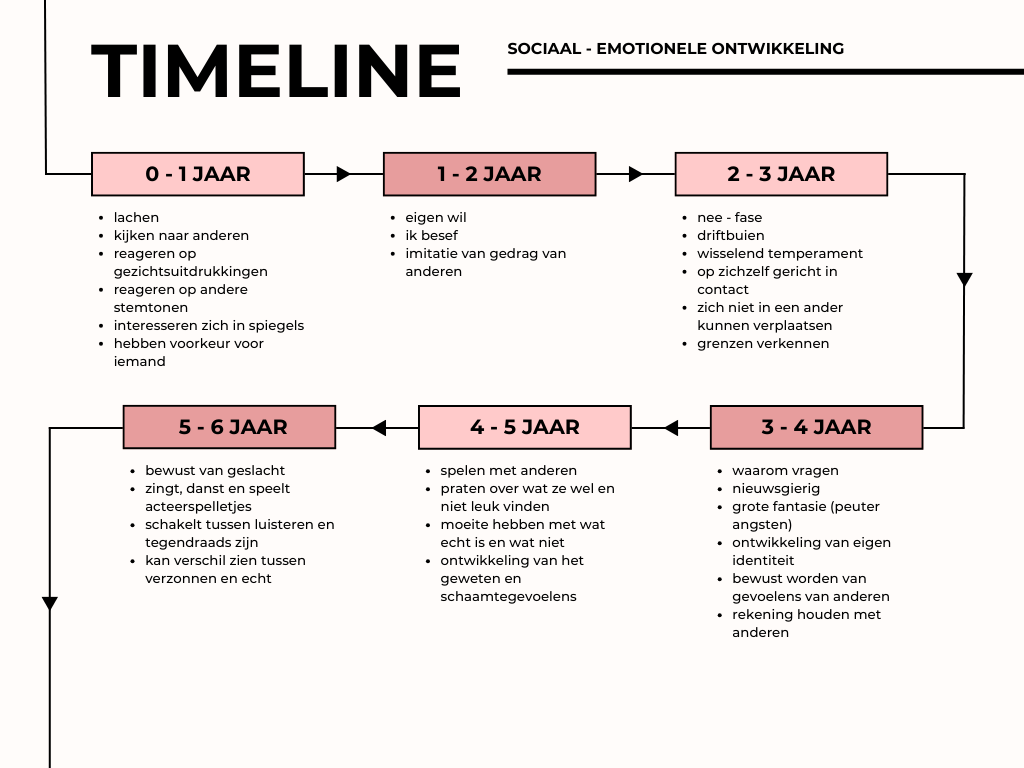
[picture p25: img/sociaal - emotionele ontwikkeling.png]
Sociaal - emotionele


Het report van het literatuuronderzoek is [hier](https://drive.google.com/file/d/1lqU_Gb7P2KewI6b2YRbHUHMy500uVC_5/view?usp=sharing) te vinden.

#### Testinterviews
**Analyse van gebruikerstesten met de interactieve beer**

Uit de testen kwamen verschillende belangrijke inzichten naar voren. Zo bleek dat kinderen verschillende niveaus van begeleiding nodig hebben. Beginners hebben nood aan een gedetailleerd stappenplan met kleine, duidelijke stappen, terwijl kinderen met meer ervaring sneller willen werken. Het systeem moet daarom adaptief zijn en begeleiding kunnen aanpassen aan het niveau van het kind. Daarnaast werd duidelijk dat de interactie soms plaatsvindt in een natte omgeving, waardoor het moeilijk kan zijn om knoppen te bedienen. Daarom is het belangrijk dat de interface waterbestendig en makkelijk schoon te maken is.

Verder bleek dat duidelijke en concrete instructies belangrijk zijn. Te complexe pictogrammen of te veel visuele elementen kunnen verwarrend zijn voor jonge kinderen. Tot slot toonde de test aan dat audiofeedback een grote meerwaarde heeft. Wanneer instructies werden voorgelezen, reageerden kinderen sneller en met meer zekerheid. Audio is daarom essentieel, zeker omdat kinderen in deze leeftijdsgroep vaak nog niet kunnen lezen. Positieve geluidjes en bevestigingen kunnen daarnaast helpen om kinderen gemotiveerd en betrokken te houden. 

**Analyse van de app-interface**

Uit de evaluatie blijkt dat ouders vooral belang hechten aan een eenvoudige, duidelijke en overzichtelijke app. De app moet snel en intuïtief werken, zodat ouders gemakkelijk taken kunnen instellen of aanpassen zonder door complexe menu’s te moeten navigeren. Daarnaast vinden ouders het belangrijk dat routines flexibel aangepast kunnen worden. Vooraf ingestelde taken zoals kleren aandoen, handen wassen of naar het toilet gaan zijn handig, maar ouders willen ook zelf taken kunnen toevoegen en de volgorde ervan aanpassen. Het is bovendien nuttig dat routines opgeslagen kunnen worden, zodat ze later snel opnieuw gebruikt kunnen worden.

Voor gezinnen met meerdere kinderen is het belangrijk dat meerdere accounts mogelijk zijn, zodat de gegevens en voortgang per kind overzichtelijk blijven. Ook moet de app toegankelijk zijn op meerdere smartphones, zodat beide ouders de verbinding met de knuffelbeer kunnen maken en de vooruitgang kunnen opvolgen. Ouders willen daarnaast de voortgang van hun kind kunnen volgen, bijvoorbeeld via visuele feedback zoals sterretjes, badges of een voortgangsbalk, en via een overzicht op langere termijn.

Verder kan het motiverend zijn wanneer kinderen zelf betrokken worden, bijvoorbeeld door de volgorde van taken te kiezen of hun voortgang op de beer te zien. Ook meldingen en tips worden als nuttig beschouwd, omdat ze ouders helpen om oefenmomenten niet te vergeten en ondersteuning bieden bij het oefenen. Tot slot moet de app duidelijk tonen of de knuffelbeer correct verbonden is en of de ingestelde routine goed is doorgestuurd, zodat ouders zeker zijn dat het systeem correct werkt.

Het report van de testinterviews is [hier](https://drive.google.com/file/d/1iAICvbYoYDdQVMLRW9RndhLdhfBj4c1h/view?usp=sharing) te vinden.

---

### Hardware en opstelling
Onderstaand schema geeft de uiteindelijke hardware-opstelling weer die gebruikt zal worden voor de realisatie van dit project. Op basis van deze opstelling werden de nodige componenten geselecteerd en aangekocht. In de volgende fase wordt de hardware opgebouwd en wordt de software ontwikkeld om het volledige systeem te testen.

Opstelling Planda

Binnen dit project worden de taakjes en bijhorende hints opgeslagen in het interne geheugen van de ESP32. Hierdoor blijft het aantal beschikbare taakjes voorlopig beperkt door de opslagcapaciteit van de microcontroller. Het gebruikte TFT-display beschikt echter over een ingebouwde SD-kaartinterface. In een toekomstige uitbreiding kan deze opslagmogelijkheid gebruikt worden om de taakjes en hints extern op te slaan, waardoor een groter aantal taakjes mogelijk wordt.

In de huidige opstelling wordt een pogo-pin connector gebruikt om de verbinding tussen de ESP32 en de componenten in de beer tot stand te brengen. Dankzij de sterke magneten in deze connector kan de aansluiting niet verkeerd gepositioneerd worden, waardoor het omwisselen van de polariteit wordt voorkomen. Daarnaast maakt de magnetische verbinding het mogelijk om de aansluiting snel te koppelen en los te maken.

Omdat het solderen van dergelijke verbindingen extra nauwkeurigheid vereist en mijn ervaring hierin beperkt is, wordt in deze projectfase een eenvoudige zelfgemaakte connector gebruikt op basis van Dupont-kabels. Deze oplossing maakt het mogelijk om de hardware flexibel aan te sluiten en eenvoudig aanpassingen uit te voeren tijdens het ontwikkelproces.

---

### Conclusies & implicaties
Uit de testen blijkt dat het concept goed werkt, maar dat enkele onderdelen nog verder verbeterd moeten worden. Zo is adaptieve begeleiding nodig afhankelijk van het niveau van het kind, zijn waterbestendige knoppen belangrijk in natte situaties en speelt audio een grote rol omdat jonge kinderen vaak nog niet kunnen lezen. 

Daarnaast blijkt dat ouders een eenvoudige en overzichtelijke app willen. Ze willen routines makkelijk kunnen instellen en aanpassen en de voortgang van hun kind kunnen volgen via visuele feedback. 

In onderstaande tabel worden de conclusies weergegeven met de bijhorende reden of onderbouwing waarop de design requirements gebaseerd zijn.

| Conclusie | Reden |
|---|---|
| Het systeem moet minimaal twee begeleidingsniveaus hebben en zich aanpassen aan het kind | Beginners hebben nood aan stap-voor-stap begeleiding, terwijl gevorderde kinderen sneller willen werken |
| Elke stap moet visueel eenvoudig en beperkt tot één actie zijn | Kinderen raken verward door complexe pictogrammen en te veel visuele elementen |
| Audio-instructies zijn essentieel en moeten standaard geïntegreerd zijn | Kinderen reageren sneller en zekerder wanneer stappen worden voorgelezen; velen kunnen nog niet lezen |
| De app moet minimalistisch en intuïtief zijn | Ouders willen snel taken kunnen instellen zonder complexe menu’s |
| Routines moeten volledig bewerkbaar zijn (toevoegen, verwijderen, volgorde wijzigen) | Ouders willen flexibiliteit in het aanpassen van dagelijkse routines |
| De app moet vooraf ingestelde standaardtaken bevatten | Ouders vinden het handig om snel te starten met basisactiviteiten zoals handen wassen en aankleden |
| Gebruikers moeten routines kunnen opslaan en hergebruiken | Dit verhoogt gebruiksgemak en voorkomt telkens opnieuw instellen |
| Ondersteuning voor meerdere kinderprofielen is noodzakelijk | Ouders willen voortgang per kind afzonderlijk kunnen opvolgen |
| De app moet toegang bieden tot beide ouders | Beide ouders willen verbinding kunnen maken en de voortgang kunnen volgen |
| Voortgang moet visueel worden weergegeven | Ouders hebben nood aan een duidelijke en overzichtelijke manier om de voortgang van hun kind snel te kunnen interpreteren via visuele elementen zoals sterretjes, badges en progress bars |
| De app moet voortgang over langere termijn tonen | Ouders willen ontwikkeling en vooruitgang over tijd kunnen opvolgen |
| De app moet herinneringen sturen voor oefenmomenten | Ouders kunnen oefenmomenten anders vergeten |
| De app moet praktische tips geven voor ouders | Ouders hebben behoefte aan ondersteuning bij het begeleiden van hun kind |
| De verbinding tussen app en beer moet duidelijk en zichtbaar zijn | Ouders willen zekerheid dat de routine correct is doorgestuurd en het systeem werkt |

> [!IMPORTANT]
> **Design Requirements**
> - 1.6 De beer biedt aangepaste begeleiding met minstens twee niveaus: een beginnersmodus met gedetailleerde stappen en een gevorderde modus met kortere instructies.
> - 1.7 Elke stap communiceert één duidelijke actie en is visueel eenvoudig en herkenbaar voor jonge kinderen.
> - 1.8 De beer leest elke stap automatisch voor via een ingebouwde speaker.
> - 4.1 De app is eenvoudig en overzichtelijk, zodat ouders snel taken kunnen instellen of aanpassen.
> - 4.2 Ouders kunnen routines volledig aanpassen door taken toe te voegen, te verwijderen of de volgorde te wijzigen.
> - 4.3 De app bevat standaardtaken.
> - 4.4 Ouders kunnen eerder ingestelde routines opslaan en opnieuw gebruiken.
> - 4.5 De app ondersteunt meerdere kinderaccounts, zodat elk kind een eigen profiel en voortgang heeft.
> - 4.6 Beide ouders kunnen via hun eigen smartphone toegang krijgen tot de beer en voortgang bekijken.
> - 4.7 Voortgang van kinderen wordt visueel weergegeven.
> - 4.8 De app toont voortgang over langere tijd.
> - 4.9 Ouders ontvangen herinneringen om oefenmomenten niet te vergeten.
> - 4.10 De app geeft praktische tips voor het oefenen van vaardigheden met het kind.
> - 4.11 De verbinding tussen de app en de beer is duidelijk zichtbaar, inclusief correcte overdracht van routines.

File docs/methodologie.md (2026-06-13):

## Methodologie

triple diamond

Het ontwikkelingsproces van Planda Beer volgde een iteratieve, gebruiksgerichte aanpak, gebaseerd op een aangepast Triple Diamond‑model. In SEM1 lag de nadruk op de discover‑ en definitiefase, waarin we de context van opvoedstress, kinderroutines en motivatie onderzochten. Deze inzichten vormden de basis voor de eerste conceptuele richting van Planda Beer.

### Discovery‑fase (SEM1)
In de discovery‑fase werd de probleemruimte rond ochtend‑ en avondroutines breed verkend. Via user interviews (N=3) met ouders en zorgverleners werden knelpunten, motivaties en strategieën in kaart gebracht. Een benchmarkingstudie (N=14) onderzocht bestaande hulpmiddelen, van educatieve apps tot fysieke routine‑tools, om marktgaten en inspiratiebronnen te identificeren.

Daarnaast werden doelgroep, context en eerste conceptideeën verkend via schetsen en vroege scenario’s. De inzichten werden samengebracht in een persona en een overzicht van noden, frustraties en kansen. Deze fase toonde vooral de nood aan een speels, fysiek én laagdrempelig hulpmiddel dat kinderen ondersteunt zonder extra stress of schermtijd.

### Definitiefase (SEM1)
In de definitiefase werd de probleemdefinitie aangescherpt en vertaald naar concrete conceptrichtingen. Een storyboard visualiseerde hoe Planda Beer een rol kan spelen in dagelijkse routines.

Vroege fysieke en visuele prototypes, van schetsmodellen tot mock-ups, werden getest in meerdere feedbackrondes (N=3). In Wave 1 werden drie conceptuele prototypes onderzocht: een beer met een scherm, een beer met fysieke voorwerpen en een beer met een oplichtend T-shirt. Het prototype met scherm kreeg de voorkeur en werd verder uitgewerkt. Parallel werd de eerste app‑interface ontwikkeld voor ouderlijke configuratie. In Wave 2 werd het geselecteerde schermprototype verder verfijnd. Hierbij werden de signalen (licht en geluid), kleurassociaties en de plaatsing van interactie-elementen geëvalueerd. Op basis van de feedback werd gekozen voor een combinatie van licht en geluid, werden kleuren afgestemd op de emotieherkenning van kinderen en werd de interactie aangepast aan hun intuïtieve links-rechtsassociaties.

#### Inzichten uit Wave 1
- Oren zijn de meest intuïtieve locatie voor knoppen.

- Interactieve elementen mogen de knuffelervaring niet verstoren.

- Licht + korte geluidjes trekken effectief aandacht.

- Geel werkt goed als startkleur; lichtgroen als voltooiingskleur.

#### Wave 2 – Verdere verdieping
- Interactie mag niet op knuffelzones (nek, armen, romp).

- Kinderen koppelen rechts aan “verder” en links aan “terug”.

- Knoppen moeten zacht, vervormbaar en veilig zijn.

Deze inzichten vormden de basis voor SEM2.

### Develop 1 (SEM2)
In deze fase werd het concept functioneel ontleed. Via storyboards, I/O‑architectuur, user flows en een morfologische matrix onderzochten we mogelijke oplossingsrichtingen. Variety prototyping en testen valideerden hypotheses rond navigatie, feedback en taakopbouw.

### Develop 2 (SEM2)
De focus verschoof naar usability en ergonomie. We voerden een antropometrische analyse uit voor de oortjes en bouwden meerdere fysieke varianten. Usabilitytests bevestigden welke vorm, drukweerstand en interactie het meest intuïtief waren.

### Develop 3 (SEM2)
Tot slot werd het product verfijnd op vlak van UX, CMF en emotionele beleving. Via CMF‑analyses, benchmarking en prototypevarianten onderzochten we tactiliteit, kleurpsychologie en lichtdoorlaatbaarheid van de oortjes. Een laatste testwave (N=3) valideerde de finale ontwerpkeuzes. Ook werd er via [vizcom](https://app.vizcom.com/workbench/ae31f0d2-f4ac-4227-a162-1b8fc1ff2d59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) naar verschillende soorten materiaal gezocht.

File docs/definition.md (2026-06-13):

## Definition

### Doelstellingen
Het hoofddoel van dit project is het ontwikkelen van een slim hulpmiddel dat de ochtendroutine voor gezinnen met jonge kinderen (2-6 jaar) verlicht. Het ontwerpproces is opgedeeld in verschillende waves om iteratief te testen en te verbeteren.

> **Wave 1**
>
>Inzicht krijgen in de huidige routines van gezinnen en eerste feedback verzamelen op low-fidelity prototypes en storyboards. De focus lag hierbij op hoe kinderen hun knuffel gebruiken en hoe ontwerpkeuzes de interactie beïnvloeden.

> **Wave 2**
>
> Het optimaliseren van de fysieke materialen en de interactievormen. Specifiek werd onderzocht hoe impulsen (licht/geluid) en beloningen de motivatie van het kind beïnvloeden en welke kleuren/materialen het gebruiksgemak verhogen.

---

### Materiaal & methoden
Het storyboard werd in een vroege fase opgesteld om de context en het gebruik van Planda tijdens de ochtendroutine te verduidelijken. Door de interactie tussen kind, ouder en knuffelbeer stap voor stap te visualiseren, werd duidelijk wanneer en hoe het product gebruikt wordt en welke acties, feedback en begeleiding daarbij nodig zijn.

Uit het storyboard kwamen verschillende aandachtspunten naar voren, zoals de rol van de ouder, het belang van duidelijke start- en eindmomenten van taakjes en de nood aan extra impulsen wanneer de aandacht van het kind verslapt. Deze inzichten vormden de basis voor het opzetten van de onderzoeks-waves.

Op basis van het storyboard werd beslist om het onderzoek gefaseerd aan te pakken: eerst door te focussen op fysieke interactie en intuïtief gebruik, en daarna op verfijning van feedback, materialen en bediening. De prototypes werden telkens opgebouwd rond specifieke momenten uit het storyboard en getest in een realistische context via observaties bij kinderen en interviews met ouders. Op die manier fungeerde het storyboard als leidraad voor zowel het onderzoek als de analyse in de verschillende waves.

Storyboard

Het onderzoek werd uitgevoerd via interviews, observaties en praktijktesten bij gezinnen thuis. Er namen ouders en kinderen tussen 2 en 6 jaar deel. In beide waves werden prototypes getest tijdens gesimuleerde ochtendroutines.

  

De protocollen voor de interviews van beide waves zijn hier te vinden:
* [Protocol wave 1](https://drive.google.com/file/d/130vRvOUCvCWISH5MEXmbPGNB_Uw2ju9m/view?usp=drive_link)
* [Protocol wave 2](https://drive.google.com/file/d/1jO9U5P_zEwsMB1liQGqoZsyC6XyTrukl/view?usp=drive_link)

Het hoofddoel van het ontwerp is dat kinderen de routine kunnen doorlopen met minimale of geen assistentie van de ouders. Om deze hoge graad van intuïtiviteit te bereiken, hebben we ons ontwikkelproces gebaseerd op de 7 Stages of Action van Donald Norman.

Bij elk prototype hebben we geanalyseerd hoe het kind de brug slaat tussen hun doel (bijv. "ik moet mijn tanden poetsen") en de fysieke handeling.

Om de interactie tussen kind en de Planda-beer te optimaliseren, gebruikten we de Wizard of Oz-methode waarbij we o.a. handmatig licht en geluid aanstuurden. Hierdoor leek de beer autonoom te reageren, wat essentieel was om de intuïtiviteit te testen volgens de 7 Stages of Action van Norman.

---

### Resultaten

**Wave 1: User feedback sessions (N=5)**

De meeste kinderen ervaren de ochtendroutine als een moment van afleiding, waarbij de focus op taken zoals tanden poetsen of aankleden snel verloren gaat. Ouders beschouwen hun constante sturing als een noodzaak om de tijdslimiet te halen, wat leidt tot een sfeer van stress.

In de eerste testen werd er getest hoe we informatie kunnen overbrengen naar de kinderen. Er werd onderzocht welke manieren het beste te begrijpen zijn voor hen, door zowel fysieke objecten als een scherm te gebruiken. 

Uit de resultaten bleek dat het scherm het meest effectief was om de taakjes over te brengen. Daarnaast merkten we dat kinderen na de ochtendroutine de knuffel ook vrij willen gebruiken om mee te spelen. Dit betekent dat het scherm op de beer gemonteerd moet kunnen worden om de taakjes uit te voeren, maar dat het daarna eenvoudig verwijderd kan worden zodat de kinderen vrij kunnen spelen.

Naast het overdragen van informatie werden ook de interactieve elementen van de beer getest. Hierbij werd gekeken naar welke onderdelen kinderen het liefst aanraken, hoe de interactie verloopt en waar de elementen het beste geplaatst kunnen worden. De testen richtten zich op de oren, armen en voeten van de beer. Hieruit bleek dat kinderen spontaan op de oren drukken, terwijl de handen en voeten problematisch zijn omdat kinderen de beer daar vaak vasthouden. Dit voorkomt onbedoelde input.

Tot slot werd onderzocht hoe kinderen interacteren met hun eigen knuffels, om hieruit inzichten te halen voor het ontwerp van de interactieve beer.

Het report van de interviews is [hier](https://drive.google.com/file/d/1wbh-eud349pPwJQK2OwwAVadwWI7WrDZ/view?usp=sharing) te vinden.

**Wave 2: User feedback sessions (N=5)**

In de tweede fase lag de focus op de verfijning van de signalen en de kleurassociaties. De cognitieve verwerking van prikkels verschilt per kind; waar de één direct reageert op licht, heeft de ander een auditieve trigger nodig om in actie te komen. 

De resultaten tonen aan dat een enkelvoudige prikkel (alleen licht) vaak wordt gemist. De combinatie van geluid en licht bleek de meest krachtige oplossing. Het geluid fungeert als aandachtstrekker, terwijl het lampje in het oor de exacte actieplaats aanwijzen.

Er werd een test uitgevoerd om te onderzoeken hoe kinderen van verschillende leeftijden kleuren associëren met emoties. Kinderen moesten emoties koppelen aan kleuren.



Kinderen zien links vaak als “terug” en rechts als “doorgaan”. Daarom is het logisch om rechts te gebruiken voor het starten en links voor beëindigen, zo wordt het makkelijker en duidelijker voor hen.

De autonomie van het kind wordt versterkt door deze directe feedbacklus. De beer fungeert als een onafhankelijke gids, waardoor de ouderlijke rol verschuift van sturende "politieagent" naar toeschouwer, wat de opvoedstress aanzienlijk verlaagt.

Het report van de interviews is [hier](https://drive.google.com/file/d/1y09vUGmh9ruJW8-vAtFctbpJqeW_Oqac/view?usp=sharing) te vinden.

---

### Reflectie

In tegenstelling tot de 7 Stages of Action, die eerder te algemeen bleken voor deze doelgroep, waren signifiers en constraints veel relevanter voor het ontwerp van een knuffel voor kinderen van 2 tot 6 jaar. Kinderen in deze leeftijdsgroep handelen voornamelijk op basis van directe visuele en fysieke aanwijzingen, waardoor het ontwerp sterk hierop werd afgestemd.

Er werd daarbij ingezet op drie kernprincipes. Ten eerste signifiers, waarbij licht in het oor aangeeft waar actie verwacht wordt, kleurgebruik betekenis communiceert (geel = start, groen = voltooid) en duidelijke iconen op het scherm de interactie ondersteunen. Ten tweede physical constraints, waarbij knoppen uitsluitend op de oren werden geplaatst omdat andere lichaamsdelen (armen, voeten en romp) tijdens het spelen vaak worden vastgehouden, wat onbedoelde input zou veroorzaken. Ten derde logical constraints, waarbij rechts staat voor verder en links voor terug, gebaseerd op natuurlijke links-rechtsassociaties die in Wave 2 werden bevestigd.

Daarnaast werd in deze fase expliciet rekening gehouden met de mentale modellen van jonge kinderen. Kinderen begrijpen technologie niet zoals volwassenen, maar redeneren vanuit herkenbare patronen zoals: 
> *“Als iets licht geeft, moet ik daar iets doen.”*

> *“Als ik op een oor druk, gebeurt er iets met de beer.”* 

> *“Rechts is vooruit, links is terug.”*

Door deze mentale modellen te analyseren en te vertalen naar concrete interacties, werd de beer voorspelbaar en begrijpelijk gemaakt, wat een cruciale voorwaarde vormt voor autonomie bij jonge gebruikers.

---

### Conclusies & implicaties
Op basis van het onderzoek en de gebruikerstesten zijn design requirements opgesteld. Deze zijn gebaseerd op de onderstaande tabel met conclusies en bijhorende redenen. Ze vormen de basis voor het verdere ontwerp en vertalen de inzichten naar duidelijke richtlijnen voor functie en gebruiksgemak, zodat het eindproduct aansluit bij de behoeften van de gebruikers.

| Conclusie | Reden uit onderzoek |
|---|---|
| Het product moet zowel licht- als geluidssignalen gebruiken. | In wave 2 bleek dat een enkelvoudige prikkel vaak gemist wordt. De combinatie van geluid en licht trok de aandacht van kinderen het meest effectief. |
| Het scherm moet eenvoudig verwijderd kunnen worden van de knuffel. | Kinderen gaven aan dat ze na de routine verder willen spelen met de knuffel. Een losneembaar scherm zorgt ervoor dat de beer ook als gewone knuffel gebruikt kan worden. |
| Interactie gebeurt via fysieke knoppen op de beer. | Tijdens de testen bleek dat jonge kinderen spontaan fysieke onderdelen van de knuffel aanraken en indrukken. Dit sluit beter aan bij hun motorische vaardigheden dan abstracte digitale bediening. |
| De knoppen worden geplaatst op locaties die gemakkelijk bereikbaar zijn voor kinderen. | Uit observaties bleek dat kinderen de oren spontaan aanraken, terwijl handen en voeten vaak worden vastgehouden tijdens het spelen. |
| De functies van de knoppen moeten overeenkomen met de verwachtingen van kinderen. | Kinderen associëren rechts spontaan met verdergaan en links met teruggaan of stoppen. |
| De actieve knop wordt verlicht. | Tijdens wave 2 bleek dat lichtsignalen kinderen helpen begrijpen waar een actie verwacht wordt. |
| De gekozen kleuren moeten aansluiten bij de betekenis die kinderen eraan geven. | Onderzoek naar kleur-emotieassociaties toonde aan dat kinderen kleuren koppelen aan bepaalde gevoelens en acties, waardoor kleuren betekenisvol kunnen worden ingezet. |
| Geluid wordt gebruikt als aandachtstrekker tijdens de routine. | Uit de testen bleek dat licht alleen niet altijd wordt opgemerkt. Geluid helpt om de aandacht opnieuw naar de taak te brengen. |
| Het product moet herkenbaar blijven als knuffel en uitnodigen tot spelen. | Kinderen hechtten veel belang aan het knuffelkarakter en wilden de beer ook buiten de ochtendroutine gebruiken. |
| De vorm moet afgestemd zijn op het gebruik door jonge kinderen. | Observaties toonden aan dat kinderen de knuffel op verschillende manieren vasthouden tijdens het spelen en gebruiken. |
| Het ontwerp moet onderhoudsvriendelijk zijn, bijvoorbeeld via een afneembare en wasbare hoes of onesie. | Omdat het product dagelijks gebruikt wordt door jonge kinderen, is hygiëne belangrijk. Een verwijderbare buitenlaag maakt reiniging mogelijk zonder de elektronica te beschadigen. |

> [!IMPORTANT]
> **Design Requirements**
> - 1.4 Het product geeft visuele en auditive feedback aan de gebruiker.
> - 1.5 Het scherm is losneembaar van het hoofdproduct.	
> - 2.2	Het product beschikt over fysieke knoppen.
> - 2.3	De knoppen zijn ergonomische en toegankelijke gepositioneerd voor de doelgroep.
> - 2.4 De knoppen zijn op een logische manier t.o.v. elkaar gepositioneerd.
> - 2.5	Lichtsignalen geven aan welke knop er moet ingeduwd worden.
> - 2.6	De kleuren van de lichtsignalen zorgen voor een duidelijke interpretatie.	
> - 2.7	Het product gebruikt geluid om de aandacht van het kind te trekken.
> - 3.2 Het product behoudt het knuffelaspect.
> - 3.3 Het product heeft een ergonomische vorm die makkelijk vast te houden is door de doelgroep.	
> - 3.4 Het product bevat onderdelen die gereinigd kunnen worden.

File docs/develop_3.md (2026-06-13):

## Development 3

### Doelstellingen
Het hoofddoel van deze fase is het analyseren van de CMF van de verschillende componenten.

---

### Materiaal & methoden

Vooraleer een CMF-analyse kon worden uitgevoerd, werden de verschillende componenten van het product eerst geëvalueerd en werd bepaald op welke onderdelen de analyse van toepassing zou zijn.

Er werd besloten om de oortjes te analyseren op basis van kleur en materiaal. Het omhulsel wordt vervolgens beoordeeld op kleur en textuur.

#### Materiaalkeuze van de oortjes
Voor de materiaalkeuze werden verschillende varianten ontwikkeld en geëvalueerd. Op basis van hun eigenschappen werden deze opties vergeleken om te bepalen welke het meest geschikt is.

#### Interviews
Voor volgende zaken werden interviews gedaan:
- Kleurkeuze van de oortjes
- Kleurkeuze van het omhulsel
- Textuurkeuze van het omhulsel

Voor de kleurkeuzes werden verschillende renders ontwikkeld voor de uiteenlopende ontwerpopties, die vervolgens werden samengebracht in een PowerPointpresentatie. Tijdens een interview werden deze varianten voorgelegd aan gebruikers, waarbij werd onderzocht welke ontwerpen als meest aantrekkelijk werden ervaren.

De PowerPointpresentaties zijn hier te vinden: [omhulsel](https://drive.google.com/file/d/1jtBIYcoHiLNUWgVYdP9SYzcHUyG76-D9/view?usp=sharing) en [oortjes](https://drive.google.com/file/d/1XNqXtDPErmhQJFLdnw9bNmKRSQDc-u7y/view?usp=sharing).

Voor de keuze van de textuur werden verschillende varianten aan gebruikers gepresenteerd. Zij konden de materialen ook zelf voelen, zodat op basis van hun ervaring de meest geschikte optie kon worden geselecteerd.

Het protocol van deze interviews is hier te vinden: [interview protocol](https://drive.google.com/file/d/1nMEvOunnXXP05v1LXsKzn6qRlS9hDP_Y/view?usp=sharing)

Het report van deze interviews is hier te vinden: [interview report](https://drive.google.com/file/d/1Gyd1z_1kM8eNMYuMG_D5NSGw8vEMbcCc/view?usp=sharing)

---

### Resultaten

#### Kleurkeuze van de oortjes
Bij de keuze van de oren was er meteen een duidelijke favoriet. Zowel de kinderen als de ouders kozen unaniem voor de optie met een zwart randje. Deze versie werd als het mooist en meest afgewerkt ervaren. Volgens hen zorgde het zwarte randje ervoor dat de oren beter zichtbaar zijn en dat de panda meer karakter krijgt.

Daarnaast sloot deze optie beter aan bij de rest van het ontwerp, waardoor de panda een meer herkenbare en samenhangende uitstraling kreeg. Het geheel oogde daardoor rustiger en aantrekkelijker dan de andere opties.

oren_zwart_randje

#### Materiaalkeuze van de oortjes
Binnen het concept van de interactieve beer zijn de oortjes niet alleen een visueel element, maar ook een fysieke interface. Omdat ze indrukbaar moesten zijn en LED-feedback moesten ondersteunen, vormden ze een belangrijk onderdeel van het CMF-onderzoek. De vorm werd al bepaald in Develop 2 op basis van ergonomie; in Develop 3 lag de focus op materiaal, tactiliteit en afwerking.

Eerst werd een 3D-geprint prototype getest. Dit gaf een goed beeld van schaal en interactie, maar het harde materiaal voelde te weinig zacht voor een knuffelproduct.

foto geprint

Daarna werd een zachter gietmateriaal getest via een mal. Dit voelde aangenamer aan, maar bleek moeilijk uit de mal te halen en sloot visueel minder goed aan bij het ontwerp qua kleur en afwerking.

foto gietmateriaal

Vervolgens werd een SLA-prototype onderzocht. Dit gaf sterke LED-visibility door het transparante materiaal, maar was te hard en niet indrukbaar, waardoor de knopfunctie verloren ging.

foto SLA foto SLA onder

Uiteindelijk werd gekozen voor silicone als eindmateriaal. Hiervoor werd een aparte gietmal ontworpen waarin silicone gegoten en uitgehard werd. 

Silicone combineert volgende belangrijke eigenschappen:
- zachtheid
- elasticiteit
- goede indrukbaarheid 
- voldoende grip

Daardoor sluit het beter aan bij de gewenste gebruikerservaring. Silicone is bovendien zeer intuïtief omdat kinderen vanzelf aanvoelen dat het indrukbaar is.

foto silicone foto silicone mal

Een nadeel is de beperkte lichtdoorlaatbaarheid, waardoor de LED minder zichtbaar wordt. Dit werd opgelost door een kleine opening in het oortje te voorzien, zodat de feedback toch duidelijk blijft.

#### Kleurkeuze van het omhulsel
Wat betreft het kleurgebruik van het omhulsel gaven de kinderen duidelijk aan dat ze een voorkeur hebben voor felle en opvallende kleuren. Van de voorgestelde opties werd vooral felroze het vaakst gekozen. Dit verschilt van de voorkeur van de ouders. Zij kiezen liever voor kleuren die beter passen bij hun interieur en minder opvallen in de leefomgeving. Hun voorkeur gaat vooral uit naar neutrale, natuurlijke kleuren en zachte pastelkleuren.

Uit de gesprekken bleek wel dat ouders bereid zijn om hierin een compromis te maken. Omdat het product in de eerste plaats bedoeld is voor kinderen, vinden zij het belangrijk dat het aantrekkelijk is voor hun kind en effectief gebruikt wordt. Als felle kleuren ervoor zorgen dat de panda vaker gebruikt wordt of meer interesse opwekt bij het kind, staan ouders ervoor open om af te wijken van hun eigen voorkeuren.

omhulsel_roze

Hoewel felroze het populairst was als kleur voor het omhulsel, moet er rekening mee gehouden worden dat enkel meisjes deelnamen aan de bevraging. Daardoor kunnen de resultaten beïnvloed zijn door persoonlijke of stereotype kleurvoorkeuren en zijn ze mogelijk niet representatief voor alle kinderen.

#### Textuurkeuze van het omhulsel
Bij de keuze van de textuur waren de meningen meer verdeeld. De antwoorden verschilden tussen de opties hout, glad en fijn ruw. Vooral de ouders gaven aan dat ze de houttextuur mooi vonden, omdat deze een warme en natuurlijke uitstraling heeft.

Er werd wel rekening gehouden met het feit dat het uiteindelijke product geen houtkleur zal hebben. Daardoor zou een houttextuur minder realistisch of passend kunnen lijken in het definitieve ontwerp. Daarom werd opnieuw gekeken naar de voorkeuren van de kinderen, aangezien zij de belangrijkste gebruikers van het product zijn.

Uit hun antwoorden bleek dat een gladdere textuur het meest in de smaak viel. Een glad oppervlak werd als aangenamer en zachter ervaren. Daarnaast zorgt een gladde afwerking voor een eenvoudiger ontwerp, waardoor het geheel minder druk oogt.

textuur_omhulsel

---

### Conclusies & implicaties
Op basis van de resultaten kan geconcludeerd worden dat er een duidelijk verschil is tussen de voorkeuren van ouders en kinderen. Ouders kiezen voor een rustige, natuurlijke en interieurgerichte uitstraling, terwijl kinderen eerder voorkeur geven aan felle kleuren, zachte materialen en speelsheid. In de uiteindelijke ontwerpbeslissingen zal er eerder worden gekeken naar de voorkeuren van het kind, aangezien het de bedoeling is dat de beer het kind gaat stimuleren / helpen.

finale_render

Tijdens deze fase zijn op basis van de conclusies uit het onderzoek verschillende design requirements opgesteld. In onderstaande tabel worden deze conclusies weergegeven, samen met de bijhorende onderbouwing.

| Conclusie | Reden |
|---|---|
| Kinderen worden sterker aangetrokken door opvallende en herkenbare visuele elementen. | Kinderen gaven duidelijk de voorkeur aan felle kleuren. Daarnaast kozen zowel kinderen als ouders unaniem voor de oortjes met een zwart randje omdat deze beter zichtbaar waren en de panda meer karakter gaven. |
| Een zachte en indrukbare interactie wordt als het meest natuurlijk ervaren voor de bediening van de oortjes. | Uit de materiaalvergelijking bleek dat silicone de beste combinatie biedt van zachtheid, elasticiteit, indrukbaarheid en grip. Kinderen voelen bovendien intuïtief aan dat het materiaal kan worden ingedrukt. |
|Het product zorgt voor duidelijke visuele lichtfeedback tijdens de interactie.|Kinderen moeten het LED-licht duidelijk kunnen zien tijdens interactie.|
| Kinderen ervaren een glad oppervlak als aangenamer dan een oppervlak met structuur. | Tijdens de interviews werd de gladde textuur het vaakst gekozen omdat deze zachter aanvoelt en het ontwerp eenvoudiger en rustiger maakt. |
| Het product is beschikbaar in verschillende kleurvarianten. | De kleurvoorkeuren werden enkel door meisjes beoordeeld. |

> [!Important]
> Design requirements
> - 3.1 Het product heeft een speels karakter door het gebruik van opvallende kleuren en herkenbare visuele kenmerken.
> - 3.5 De oortjes hebben een zachte en elastische interface.
> - 1.4 Het product geeft visuele feedback aan de gebruiker.
> - 3.6 Het omhulsel voelt glad aan.
> - 3.7 Het product is beschikbaar in verschillende kleurvarianten.

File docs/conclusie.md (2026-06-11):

## Conclusie
Planda is een interactieve knuffelbeer die kinderen tussen twee en zes jaar ondersteunt bij dagelijkse routines en taakjes, zoals tandenpoetsen, opruimen of schoenen aantrekken. Uit het vooronderzoek bleek dat jonge kinderen zich tijdens dergelijke activiteiten vaak laten afleiden, weerstand bieden of moeite hebben om taken zelfstandig af te werken. Dit kan leiden tot frustratie en stress bij ouders. Het doel van Planda is om deze uitdagingen aan te pakken door kinderen op een speelse en motiverende manier te begeleiden.

Wij geloven dat Planda een sterke oplossing vormt voor het geschetste probleem omdat het inspeelt op zowel de behoeften van het kind als die van de ouder. Kinderen krijgen ondersteuning via duidelijke stap-voor-stap begeleiding, terwijl ouders minder voortdurend moeten aansturen. Hierdoor wordt niet alleen de kans vergroot dat taken succesvol worden uitgevoerd, maar wordt ook de zelfstandigheid van het kind gestimuleerd.

In onderstaande afbeelding worden de verschillende componenten van Planda weergegeven.

Planda met annotaties

Om de taken duidelijk te maken aan het kind, maakt Planda gebruik van een scherm waarop de verschillende stappen worden weergegeven aan de hand van GIF's. Hierdoor kunnen ook kinderen die nog niet kunnen lezen de instructies begrijpen. Het scherm en de elektronica worden beschermd door een stevige case. Deze zorgt ervoor dat het product bestand is tegen het dagelijkse gebruik door jonge kinderen en voorkomt dat zij rechtstreeks aan de elektronische componenten kunnen komen. Daarnaast kreeg de case een opvallende kleur, zodat het scherm beter opvalt en het product een speelse uitstraling krijgt die aansluit bij de doelgroep.

Hoewel dit niet werd gerealiseerd in het uiteindelijke prototype, werd binnen het concept ook voorzien dat de beer een afneembare onesie zou dragen. Deze onesie kan eenvoudig verwijderd en gewassen worden, waardoor het product hygiënisch blijft tijdens dagelijks gebruik door jonge kinderen. De case met het scherm en de elektronica zou daarbij met een sterke magneet aan de beer bevestigd worden. Hierdoor kan de case eenvoudig verwijderd worden wanneer de onesie gewassen moet worden, terwijl ze tijdens normaal gebruik stevig op haar plaats blijft zitten. Dit verhoogt zowel het onderhoudsgemak als de praktische bruikbaarheid van het product.

Planda met onesie

Naast visuele begeleiding wordt ook gebruikgemaakt van geluidseffecten en liedjes. Deze elementen zorgen ervoor dat het uitvoeren van een taak minder aanvoelt als een verplichting en eerder als een leuke activiteit. Op die manier wordt de motivatie van het kind verhoogd en blijft de aandacht langer behouden.

De oren van de beer dienen als knoppen waarmee het kind met Planda kan communiceren. Deze zijn gemaakt uit doorzichtige silicone. Dit materiaal beschermt de onderliggende elektronica, voelt zacht aan en laat het licht van de ingebouwde ledjes door. Hierdoor blijven de knoppen duidelijk zichtbaar en gemakkelijk bruikbaar voor jonge kinderen. Eén oor dient om verder te gaan naar de volgende stap, terwijl het andere oor extra uitleg of motivatie biedt wanneer het kind hier nood aan heeft. Door deze eenvoudige bediening kan het kind zelfstandig gebruikmaken van het systeem.

Om extra begeleiding te bieden, zijn beide oren voorzien van ledverlichting. Wanneer een knop wordt ingedrukt, knippert deze kort als visuele bevestiging dat de knop is ingedrukt. Daarnaast bevat de neus van de beer een groen ledlicht dat oplicht wanneer een taak succesvol werd afgerond. Deze onmiddellijke positieve feedback geeft het kind een gevoel van succes en stimuleert om verder te gaan met de volgende taak.

Naast de knuffelbeer werd ook een ondersteunende mobiele app ontworpen voor ouders. Via deze app kunnen takenreeksen worden samengesteld, aangepast en doorgestuurd naar de beer. Daarnaast biedt de app mogelijkheden om de voortgang van het kind op te volgen, meerdere profielen te beheren, herinneringen te krijgen voor oefenmomenten, … . Hierdoor kan Planda eenvoudig worden afgestemd op de specifieke behoeften van elk gezin.

De app is hier te vinden: [Planda App](https://www.figma.com/make/hH7P8G2qhJlz6ltt2GSOgT/Morning-Routine-Planner-App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)

Op basis van de vooropgestelde [design requirements](design_requirements.md) geloven wij dat Planda een geschikte oplossing biedt voor het ondersteunen van jonge kinderen bij dagelijkse routines en taken. Door duidelijke begeleiding, motiverende feedback en een speelse vormgeving te combineren, helpt Planda kinderen om taken zelfstandiger uit te voeren en vermindert het tegelijkertijd de nood aan voortdurende tussenkomst van ouders.

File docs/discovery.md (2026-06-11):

## Discovery 

### Doelstellingen

Het hoofddoel van de discovery-fase was om beter te begrijpen waar opvoedstress bij jonge ouders vandaan komt en hoe een slim product kan helpen om die stress te verminderen, het kind zelfstandiger te maken en positieve ontwikkeling te stimuleren. 
Hierbij zijn de deelvragen:
- Welke momenten veroorzaken de meeste opvoedstress bij ouders?
- Hoe reageren kinderen bij het uitvoeren van deze taak?
- Welke taken kan het kind al zelfstandig uitvoeren?
- Welke oplossingen bestaan er al?
- Voor welke (dagelijkse) taak zijn nog het minst oplossingen beschikbaar?

---

### Materiaal & methoden

Dit onderzoek werd uitgevoerd met twee onderzoeksmethoden: interviews en een benchmarkingonderzoek.
Voor de interviews werden personen gekozen die direct betrokken zijn bij opvoedstress. Dit waren ouders met een kind tussen 2 en 6 jaar. Met hen werden semigestructureerde interviews gehouden. Dat betekent dat er vooraf hoofdvragen waren opgesteld, maar dat er tijdens het gesprek ruimte was om door te vragen. De interviews duurden gemiddeld 40 minuten en vonden plaats online en face-to-face. Met toestemming zijn de gesprekken opgenomen en later uitgewerkt. De antwoorden werden daarna geanalyseerd en vergeleken met elkaar.

Het volledige interviewprotocol is hier te vinden: [interview protocol](https://drive.google.com/file/d/1N_GjyhnOHkRdai5fe6EW2gFWemPGeeNa/view?usp=sharing).

Naast de interviews werd er een benchmarkingonderzoek gedaan om beter te begrijpen welke bestaande oplossingen er al zijn en op welke taken nog weinig ondersteuning wordt geboden. Hierbij werd naar bestaande producten gekeken die de opvoedstress zouden kunnen verminderen. Informatie kwam uit openbare bronnen, zoals websites en blogs. Vervolgens werden de oplossingen vergeleken op basis van hun sterke en zwakke punten. 

Het protocol van deze benchmarking is hier te vinden: [benchmarking protocol](https://drive.google.com/file/d/1VPV1awJDa64VDqinm8LVtdigFpOs-lXI/view?usp=sharing).

Door beide methoden te gebruiken konden zowel de ervaringen van ouders als informatie over bestaande oplossingen worden meegenomen. Hierdoor werd het onderwerp van verschillende kanten onderzocht.

---

### Resultaten

**Interviews** 

Uit de interviews blijkt dat opvoedstress bij jonge ouders vooral voorkomt tijdens dagelijkse routines waarbij tijdsdruk een grote rol speelt. Vooral de ochtend wordt als het meest stressvolle moment ervaren, omdat ouders in korte tijd veel taken moeten uitvoeren, zoals zichzelf klaarmaken, het kind aankleden, ontbijten, tanden poetsen en op tijd vertrekken naar school of werk. Stress ontstaat daarbij niet alleen door het gedrag van het kind, maar ook door externe factoren zoals werkdruk, deadlines of onverwachte taken, zoals iets meegeven voor school of opvang regelen bij ziekte.
De belangrijkste momenten van stress zijn de ochtend- en avondroutine, en taken zoals eten en aankleden waarbij kinderen traag of afgeleid zijn. Het gedrag van kinderen, zoals tegenwerken, afleiding zoeken of afhankelijkheid van de ouder, heeft een directe invloed op hoe ouders zich voelen. Sommige kinderen reageren emotioneel op gehaaste of boze ouders, wat de stress verder verhoogt. Hoewel veel kinderen al een deel van de taken zelfstandig kunnen uitvoeren, blijft begeleiding vaak nodig, omdat afleiding en motivatie soms ontbreken.

> *“Als ze iets in haar hoofd heeft, wilt ze dat direct doen.”*

>*“Als de mama boos wordt, zal Claire verdrietig worden.”*

>*“Maar ik moet het zo blijven herhalen wel, want als ik haar gewoon laat doen, dan loopt ze hier weer als een kip zonder kop door het huis.”*

Ouders zien verschillende manieren om deze stress te verminderen. Structuur en voorspelbaarheid, bijvoorbeeld door duidelijke schema’s of visuele hulpmiddelen, helpen kinderen beter te begrijpen wat er van hen verwacht wordt. Uit de interviews bleek echter dat structuur alleen niet altijd voldoende is. Een ouder gaf aan dat een klassieke routineplanner weinig motiverend werkt omdat kinderen deze na verloop van tijd negeren.

>*“Een ochtendroutineplanner heeft weinig motivatie, dan kijkt ze daarna. En dan denkt ze waarschijnlijk: Maar ik weet dat al hè.”* 

Beloningssystemen kunnen de motivatie van het kind vergroten, terwijl gebruiksvriendelijke en duurzame hulpmiddelen ervoor zorgen dat de routines soepel verlopen.
Het gewenste eindresultaat van de ouders is dat de dagelijkse routines rustig en gestructureerd verlopen, zonder geschreeuw of haast. Het kind voert taken zelfstandig uit, zonder voortdurende herhaling of aansporing, en er ontstaat meer tijdsbesef en minder spanning voor zowel ouder als kind. Op deze manier kan een slim hulpmiddel bijdragen aan stressvermindering bij ouders, meer zelfstandigheid bij kinderen en een positieve, plezierige sfeer in het gezin.

Het report van de interviews is [hier](https://drive.google.com/file/d/19u9PNdlWeaDVB6IC4Rpc8PkJ9rHKdnLq/view?usp=sharing) te vinden.

**Benchmarking**

Uit de analyse is gebleken dat er al veel mogelijke oplossingen bestaan voor het eten en in bad gaan. Ook voor tanden poetsen zijn de twee belangrijkste aspecten, namelijk de duur van het poetsen en het daadwerkelijke poetsen zelf, al omgezet naar oplossingen. 

Voor aankleden, opruimen en de ochtendroutine liggen er echter nog kansen om originelere en soms effectievere producten te ontwerpen. Bij aankleden en de ochtendroutine wordt momenteel meestal gewerkt met pictogrammen of checklists. Voor sommige kinderen blijkt dit niet motiverend genoeg te zijn om consequent te gebruiken. Bij opruimen geld iets soortgelijks, maar dan met behulp van labels. 

Wat slapen en opstaan betreft, bestaat er al een breed aanbod aan slaaptrainers, met verschillende opties en ontwerpen. Omdat dit product effectief en goed ontwikkeld is, vormt deze taak geen probleem meer.

Het report van de benchmarking is [hier](https://drive.google.com/file/d/1ek-WHoF4-XrpG6pTKncxjXwMrDPfr108/view?usp=sharing) te vinden.

---

### Conclusies & implicaties

Uit de analyse van de interviews en het benchmarkingonderzoek volgt dat er bij de ochtendroutine nog wat problemen liggen. Op dit onderwerp zal er dus verder gewerkt worden. Bij het verdere proces zal er rekening gehouden worden met design requirements die gebasseerd zijn op onderstaande conclusies:
| Conclusie | Reden |
|---|---|
| Het hulpmiddel moet op een duidelijke en motiverende manier taken visueel weergeven. | Ouders geven aan dat chaos en tijdsdruk de grootste stress veroorzaken, vooral in de ochtendroutine. |
| Het hulpmiddel moet kinderen ondersteunen zonder volledig over te nemen, zoals stap-voor-stap instructies en visuele hints geven. | Ouders willen dat hun kinderen steeds meer zelfstandig uitvoeren, maar hebben nog begeleiding nodig. |
| Het hulpmiddel moet aanpasbaar zijn, zodat ouders zelf de volgorde van taken, tijden of beloningen kunnen instellen. | Elke ouder en elk kind heeft unieke routines en voorkeuren. |
| Het ontwerp moet intuïtief en eenvoudig te begrijpen zijn zodat het kind en ouder het makkelijk kunnen gebruiken. | Ouders willen geen extra stress door ingewikkelde of onduidelijke hulpmiddelen. |
| Het hulpmiddel moet speels zijn of beloningssystemen of gamification-elementen bevatten om de zelfstandigheid te stimuleren en motivatie te verhogen. | Kinderen zijn vaak afgeleid of weinig gemotiveerd om taken zelfstandig uit te voeren. |

> [!IMPORTANT]
> **Design Requirements**
> - 1.1 Het product geeft taken duidelijk en motiverend weer.
> - 1.2 Het product ondersteunt de gebruiker tijdens de activiteit.
> - 1.3 Het product is personaliseerbaar.
> - 2.1 Het product is intuïtief en eenvoudig te gebruiken.
> - 3.1 Het product heeft een speels karakter.

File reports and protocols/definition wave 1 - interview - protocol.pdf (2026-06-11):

# Interview protocol Wave 1

## Project informatie

Projectnaam: Planda
Dit project richt zich op het ontwikkelen van een slim product om de opvoedstress bij ouders met jonge kinderen te helpen reduceren tijdens de ochtendroutine.

Interviewer: Luna Van Tittelboom (luna.vantittelboom@ugent.be), Bram Eeckhout (bram.eeckhout@ugent.be), Doren Vermaut (doren.vermaut@ugent.be), Studenten Industrieel Ingenieur Industrieel Ontwerpen

## Doelstelling en kadering

In dit project wordt gewerkt aan een slim hulpmiddel dat ouders met jonge kinderen helpt om de ochtendroutine te verlichten. Om de noden van de doelgroep beter te begrijpen, worden testinterviews afgenomen met ouders en hun jonge kinderen. Het doel van deze interviews is om inzicht te krijgen op hun huidige routine en feedback te krijgen op prototypes. Op basis van deze feedback worden verdere iteraties uitgevoerd om de gebruikservaring te optimaliseren.

## Respondenten

De respondenten zijn ouders met een kind van 1 tot en met 6 jaar.

Steekproefomschrijving (N = 4)

pseudonym | respondent type | interview datum | interview locatie
| Sofie: mama van Marit Marit: 6 jaar | 30/11/2025 | Thuis
| Kaat: mama van Claire Claire: 4 jaar | 30/11/2025 | Thuis

Sofie & Marit

Kaat & Claire

Emiel & Lowie | 3 & 1 jaar | 30/11/2025 | Thuis

## Onderzoeksvragen

Hoe gebruiken kinderen hun knuffel in het dagelijkse leven, en welke kenmerken van dat gebruik kunnen de werking van een interactieve knuffelbeer beïnvloeden?

Hoe kunnen ontwerpkeuzes in een interactieve knuffelbeer het gebruiksgemak, de zelfstandige bediening en de betrokkenheidsreacties van kinderen optimaliseren?

## Overzicht van de discussiegids en tijdsinschatting

- Deel 1 – Introductie (5’)
- Deel 2 – Voorstelling Interviewee (5’)
- Deel 3 – Knuffel gebruik (5’)
- Deel 4 – Prototypes (10’)
- Deel 5 – Situatie (15’)
- Deel 5 – Wrap-up (5’)

## Discussiegids

Introductie (5 min.)

Bedankt voor je deelname aan dit onderzoek.

Ik zal starten met het project en mezelf kort voor te stellen.

Ik ben <eigen naam> en ik studeer aan de universiteit Gent campus Kortrijk met afstudeerrichting industrieel ingenieur industrieel ontwerpen.

Deze afstudeerrichting focust zich op het bedenken en verbeteren van producten. Daarom hebben we het vak Project Gebruiksgericht Ontwerpen, waarin we aan de hand van een specifiek thema een prototype moeten maken.

Het thema van dit jaar is opvoedstress. Er moet een slim product worden ontworpen voor ouders die stress ervaren bij de opvoeding van hun kind(eren) tussen de 2 en 6 jaar. Het doel van dit product is om die stress te verminderen. Samen met mijn teamgenoten werken wij aan een product voor de ochtendroutine en eventueel ook de avondroutine.

Dit gesprek is belangrijk omdat ik wil begrijpen hoe kinderen reageren op knuffels en onze voorlopige prototypes.

Ik start dit gesprek graag met enkel algemene vragen en vragen over het gebruik van een knuffel en dan vervolgens stel ik onze eerste prototypes voor, zodat we de bevindingen onmiddellijk in de praktijk kunnen uittesten.

Ik ben erg benieuwd naar uw inzichten en ervaringen. Er zijn geen juiste of foute antwoorden. Ik ben gebaat bij uw oprechte feedback rond de topics die we zullen behandelen.

Ik wil zeker nog onderstrepen dat alles wat straks in het gesprek aan bod komt in absolute confidentialiteit behandeld wordt. We zijn als studenten aan de Ugent namelijk gebonden aan de Europese privacy richtlijnen. Voor de synthese met de inzichten en aanbevelingen worden individuele meningen sowieso ook geanonimiseerd. Je naam zal met andere woorden niet gekoppeld worden aan specifieke uitspraken. Een meer gedetailleerde beschrijving van onze intenties, verwerking van gegevens, en algemeen beleid kan je nalezen in de ‘Informed Concent’. Voor we van start kunnen met het interview, heb ik jouw expliciet akkoord nodig met dit document.

Ten slotte, had ik je ook graag gevraagd of ik straks dit gesprek mag opnemen met een voice recorder, om ons gesprek te kunnen herbeluisteren wanneer de analyse wordt gemaakt. Uiteraard wordt deze opname niet gedeeld met derden, en verwijderd na afloop van het project. Als u hiermee akkoord gaat, stel ik voordat we het interview beginnen.

----------------------------[invullen informed consent & start recording] ----------------------------

Contextuele vragen

Voorstelling Interviewee (5 min)

Alvorens we in de materie duiken, wil ik graag eerst even kennismaken.

- Kunt u kort uzelf voorstellen?
- Wat is uw naam, uw leeftijd, uw gezinssituatie, uw job, eventueel hobby’s (die buitenshuis zijn)?
- Kunt u me iets meer vertellen over hoe de ochtend er bij u uit ziet?

Knuffelgebruik (5 min.)
- Hoe frequent worden knuffels overal mee naartoe gesleurd?
- Is het altijd dezelfde knuffel?
- Hoe worden ze vastgenomen?
- Zijn er gewoontes (habits) van de kinderen die de werking van de beer zouden beïnvloeden?

Prototype (10 min.)
- Waar worden de knoppen het best gepositioneerd?
- Wat is aangenamer voor het kind: een blijvend scherm of een scherm dat eraf kan gehaald worden?
- Waar reageren kinderen beter op: een scherm of extra fysieke producten?
- Hoe reageren kinderen op impulsen die door de beer gegeven worden?
- Impulsen tijdens taakjes om te stimuleren
- Impulsen om de aandacht te trekken om aan een taakje te beginnen
- Hoe kunnen de kinderen de beer perfect gebruiken zonder enige externe begeleiding/hulp?

Scenario (15 min.)
Het is ochtend. Het kind moet zich klaarmaken voor school. Op de knuffelbeer verschijnen de verschillende stappen die het kind moet doorlopen.

Wrap-up (5 min.)

Wenst u zelf nog zaken toe te voegen?

De belangrijkste zaken die ik heb geleerd uit dit interview zijn, …
Heb ik het juist begrepen als …?
Wat zijn de belangrijkste elementen waarvan u denkt dat ik die het meest zou moeten onthouden?

Zou u graag op de hoogte blijven van de resultaten of toekomstige gebruikerstests? Bedankt voor uw tijd en medewerking.

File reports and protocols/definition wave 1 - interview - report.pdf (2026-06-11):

# Interview report Wave 1

Project informatie

Projectnaam: Planda

Dit project richt zich op het ontwikkelen van een slim product om de opvoedstress bij ouders met jonge kinderen te helpen reduceren tijdens de ochtendroutine.

Interviewer: Luna Van Tittelboom (luna.vantittelboom@ugent.be), Bram Eeckhout (bram.eeckhout@ugent.be), Doren Vermaut (doren.vermaut@ugent.be), Studenten Industrieel Ingenieur Industrieel Ontwerpen

Doelstelling en kadering
In dit project wordt gewerkt aan een slim hulpmiddel dat ouders met jonge kinderen helpt om de ochtendroutine te verlichten. Om de noden van de doelgroep beter te begrijpen, worden testinterviews afgenomen met ouders en hun jonge kinderen. Het doel van deze interviews is om inzicht te krijgen op hun huidige routine en feedback te krijgen op prototypes. Op basis van deze feedback worden verdere iteraties uitgevoerd om de gebruikservaring te optimaliseren.

Respondenten

De respondenten zijn ouders met een kind van 2 tot en met 6 jaar.

De interviews duren 45 minuten en worden afgenomen van 22/11/2025 tot 30/11/2025.

Steekproefomschrijving (N = 4)

pseudoniem | respondent type | interview datum | interview locatie
| Sofie: mama van Marit Marit: 6 jaar | 30/11/2025 | Thuis
| Kaat: mama van Claire Claire: 4 jaar | 30/11/2025 | Thuis

Sofie & Marit

Kaat & Claire

Emiel en Lowie | 3 en 1 jaar | 30/11/2025 | Thuis

Onderzoeksvragen
Hoe gebruiken kinderen hun knuffel in het dagelijkse leven, en welke kenmerken van dat gebruik kunnen de werking van een interactieve knuffelbeer beïnvloeden?
Hoe kunnen ontwerpkeuzes in een interactieve knuffelbeer het gebruiksgemak, de zelfstandige bediening en de betrokkenheidsreacties van kinderen optimaliseren?

Protocol
definition wave 1 – interview - protocol (https://drive.google.com/file/d/130vRvOUCvCWISH5MEXmbPGNB_Uw2ju9m/view?usp=sharing)

Storyboard
Het onderdeel ‘Definition’ van deze opdracht start met het maken van een storyboard. Hieruit worden enkele design challenges al direct duidelijk en is het ook duidelijk wat de context is waarin ons product gebruikt zal worden. Deze inzichten worden verder gebruikt in het maken van onze prototypes.


Prototypes
Voordat de prototypes voor de eerste wave gemaakt worden, worden er al enkele zaken mondeling besproken die we zeker willen testen. Bij het maken van de prototypes wordt er aandacht besteed aan:
1) De prototypes moeten voldoende van elkaar verschillen
2) De prototypes moeten op een zinvolle manier van elkaar verschillend


Interview analyse
Analyse uitgevoerd door Bram

### 1. Knuffelgebruik

Omdat prototype 1 uit karton bestaat, was het voornamelijk bruikbaar om de plaatsing en oriëntatie van de knoppen te evalueren en om de interactie tussen het kind en de beer te observeren. Het prototype bleek echter ongeschikt om het gebruik als echte knuffel te testen. Om toch inzicht te krijgen in knuffelgedrag, werd daarom het gedrag van de kinderen met hun eigen knuffels geobserveerd.
Uit deze observaties kwam naar voren dat het oudste kind minder gehecht of afhankelijk lijkt van een knuffel dan het jongste. Daarnaast werd ook een duidelijk verschil zichtbaar in de manier waarop ze met hun knuffels omgaan. Waar het oudste kind de beer enkel af en toe gebruikt, neemt het jongste kind de knuffel overal mee naartoe.
Er werd ook opgemerkt dat het jongste kind intensiever met de knuffel omgaat. Vooral kleinere of uitstekende onderdelen van de teddy worden vaak vastgenomen, eraan getrokken en soms zelfs in de mond gestoken. Dit gedrag toont aan dat deze onderdeeltjes een bijzondere aantrekkingskracht hebben en anders worden behandeld dan de rest van de knuffel.
Deze inzichten zijn belangrijk en worden meegenomen bij het ontwerpen van de prototypes in de tweede wave.

### 2. Fysieke componenten van de prototypes

Eerst werd aan de kinderen uitgelegd wat de blauwe en gele knop betekenen, zodat ze de functie ervan goed begrepen. Daarna werd op een speelse manier onderzocht welke knop de kinderen intuïtief zouden indrukken bij specifieke instructies.
In een volgende stap werden verschillende dagdagelijkse situaties nagebootst, waarbij geobserveerd werd hoe de kinderen hierop reageerden. De gekozen taken waren: een jas aantrekken om naar buiten te gaan, speelgoed opruimen en een tussendoortje eten. Voor elke taak werd een andere positie van de knoppen gebruikt, namelijk op de voetjes, in de hand of op het oor van de beer. Op die manier kon worden nagegaan of de oriëntatie van de knoppen invloed heeft op het gebruik en het begrip. Hieruit bleek dat de oren en de voeten de beste keuze zijn.
Tot slot werd onderzocht of het display best op de knuffel zelf wordt geïntegreerd of op een vaste externe locatie. Hiervoor werd een tablet met tape tijdelijk op de beer bevestigd. Uit de observaties bleek dat de kinderen het scherm liever niet op de knuffel willen. Tegelijkertijd werd ook vastgesteld dat het soms moeilijk is om de aandacht van de kinderen opnieuw naar het scherm te richten wanneer dit zich op afstand bevindt.

Analyse uitgevoerd door Luna

### 1. Knuffelgebruik

Uit de interviews komt naar voren dat beide kinderen veel waarde hechten aan hun knuffels, maar dat ze deze op verschillende manieren gebruiken.
Bij één kind blijven de knuffels meestal op de slaapkamer. De knuffels worden soms nog meegenomen naar andere kamers, bijvoorbeeld om mee te kijken naar televisie of om te spelen bij een broer of zus, maar dit gebeurt minder vaak dan vroeger. Thuis is er een afspraak dat de knuffels boven blijven, al wordt hier soms van afgeweken. Dit kind heeft drie favoriete knuffels en vertoont geen gedrag dat een elektronische knuffel zou kunnen beschadigen, zoals bijten of trekken aan onderdelen.
Bij het andere kind wordt de knuffel veel intensiever gebruikt. De knuffel gaat bijna overal mee naartoe: van de zetel naar de auto, en vaak ook mee tijdens de rit naar school. Om te voorkomen dat de knuffel verloren raakt, proberen de ouders het gebruik te beperken tot de auto. Het gaat steeds om dezelfde knuffel. Er is een duidelijke gewoonte om de knuffel te gebruiken om het kind te troosten wanneer het verdrietig is.
Tijdens het observeren van de kinderen hoe ze hun knuffelbeer vasthouden, valt op dat deze voornamelijk werd opgepakt aan de arm of voet en soms werd de beer dan nadien nog vastgehouden aan de nek tijdens het wandelen.

### 2. Fysieke componenten van de prototypes

Uit de interviews komt naar voren dat ouders verschillende overwegingen hebben bij het gebruik van de knuffelprototypes. De knuffel beschikt over twee knoppen: één om aan te geven dat een taak klaar is en één om hulp te vragen. De ouder denkt dat de oortjes het meest geschikt zijn voor de knoppen, omdat deze rechtop staan en gemakkelijk in te drukken zijn. De handjes zouden ook kunnen, maar de voetjes lijken minder praktisch vanwege hun neerwaartse positie. Ook over het scherm zijn er duidelijke voorkeuren. Een afneembaar scherm wordt als praktischer ervaren: het maakt de knuffel zachter om mee te slapen en kan ’s avonds losgemaakt en ’s ochtends weer aangebracht worden. Indien het scherm geïntegreerd wordt, moet dit echt zacht aanvoelen, alsof het in de buik verzonken zit. Daarnaast wordt erop gewezen dat de knuffel regelmatig gewassen moet kunnen worden, wat meegenomen moet worden bij het ontwerp.
Tot slot wordt besproken of het systeem beter kan werken met een scherm of met fysieke objecten die aan de knuffel bevestigd kunnen worden. De ouder geeft aan dat fysieke objecten leuk kunnen zijn, maar snel verloren raken. Een digitale oplossing wordt overzichtelijker gevonden.

### 3. Situatie

Voor de eerste situatie werd de beer met een scherm getest. Op het scherm verschenen drie taken die het kind moest uitvoeren: haar kammen, tanden poetsen en de rugzak nemen. Het kind moest telkens op de gele knop drukken om te starten en op de blauwe knop wanneer de taak klaar was. De knoppen zaten op de oren, handen en voeten van de beer. Opvallend was dat beide kinderen vooral de knoppen op de oren gebruikten. De taken werden vlot uitgevoerd.

In de tweede situatie werd de beer met fysieke producten getest. De beer sprak hier zelf uit welke taken moesten gebeuren: opnieuw haar kammen, tanden poetsen en de rugzak nemen. Deze keer waren er twee knoppen: een blauwe en een groene, die alleen op de oren en voeten zaten omdat de handen nodig waren om de producten te plaatsen. Ook hier gebruikten de kinderen vooral de knoppen op de oren. De taken werden opnieuw goed uitgevoerd, maar het duurde wel iets langer dan bij de versie met het scherm.

Analyse uitgevoerd door Doren

Tijdens Wave 1 voerde ik verschillende observaties en experimenten uit om beter te begrijpen hoe jonge kinderen interageren met een interactieve knuffelbeer. Al snel werd duidelijk dat zowel een geïntegreerd als een extern scherm ook nadeel met zich meebrengt. Kinderen gebruiken hun knuffels op een speelse, vaak ruwe manier: ze sleuren ermee rond, gooien ermee, knijpen erin of nemen ze mee in bed. Een harde schermcomponent is daardoor niet alleen fragiel, maar vermindert ook sterk de zachtheid, knuffelbaarheid en troostende waarde die essentieel zijn voor dit type product. Dit bevestigde dat een meer subtiele en fysieke digitale ondersteuning nodig is—zonder het scherm als centraal element.
Daarnaast observeerde ik dat kinderen bijzonder sterk reageren op lichtprikkels. Wanneer een symbool op de T-shirt van het prototype werd verlicht, werd hun aandacht spontaan naar dat specifieke element getrokken. Dit was nog duidelijker wanneer het licht een zacht flikkerend of animerend effect had. Het licht fungeerde dus niet enkel als aanwijzing, maar ook als uitnodiging tot interactie. Deze bevinding is belangrijk voor de verdere ontwikkeling: licht kan een krachtig, niet-intrusief communicatiemiddel zijn dat intuïtief begrepen wordt door kinderen. Tijdens het experiment plaatste ik een intern lichtje achter een specifiek symbool op het T-shirt van de beer, zoals een tandenborstel of een truitje. Ik vroeg vervolgens aan het kind wat de beer volgens hen “bedoelde”. In alle gevallen begrepen de kinderen onmiddellijk welke handeling gekoppeld was aan het oplichtende symbool: bij een tandenborstel verwezen ze spontaan naar tanden poetsen, en bij een truitje begonnen ze over kleren aandoen. Dit toont aan dat de lichtanimatie niet alleen de aandacht trekt, maar ook effectief functioneert als een intuïtieve visuele aanwijzing die kinderen helpt om de gewenste routinehandeling te interpreteren en te verwoorden.
Op basis van deze inzichten werd een nieuw prototype ontwikkeld dat volledig losstaat van een scherminterface. De knuffelbeer bevat interne LED-belichting die door middel van eenvoudige animaties taken visueel ondersteunt. Voor de volgende iteratie wordt overwogen om dit principe door te trekken naar de knoppen in de handjes van de beer: door kleine lichtjes te integreren die subtiel flikkeren, worden kinderen gestimuleerd om op de juiste plaats te drukken. Dit maakt de interactie niet alleen duidelijker maar ook speelser en aantrekkelijker. Het helpt hen bovendien te begrijpen waar ze de beer moeten bedienen, zonder dat dit verbaal hoeft uitgelegd te worden. Om de modulariteit te behouden, werd gekozen voor een T-shirt waarop taakjes met velcro bevestigd kunnen worden. Zo kan de ouder eenvoudig wisselen tussen routines (zoals week- of weekendroutines, of taken die passen bij een bepaalde leeftijd). Het interne licht fungeert als dynamische aanwijzer die precies dat taakje laat oplichten dat op dat moment relevant is. Hierdoor blijft het ontwerp flexibel en groeit het mee met het kind, zonder aan zachtheid of speelsheid in te boeten.
Uit dit onderzoek komen twee belangrijke designrichtlijnen naar voren:
1. Technologische elementen moeten zo geïntegreerd worden dat de zachtheid en knuffelbaarheid van de beer behouden blijven.
2. De functionaliteit moet modulair, intuïtief en evolueerbaar zijn, zodat de beer meegroeit met het kind en tegelijk bestand blijft tegen intensief speels gebruik.

De toevoeging van lichtinteractie—en het aantrekkelijke effect dat dit heeft op de aandacht en handelingen van kinderen—speelt hierbij een cruciale rol. Deze inzichten vormen samen een onderbouwde richting voor de ontwikkeling van ons totaalconcept, en leggen een waardevolle basis voor de ontwerpkeuzes en experimenten die in Wave 2 verder worden uitgewerkt.

Conclusie
De analyse van Wave 1 toont duidelijke patronen in zowel het knuffelgebruik van jonge kinderen als hun interactie met de eerste prototypes. Kinderen hechten sterk aan hun knuffel, maar de manier waarop ze ermee omgaan verschilt aanzienlijk per leeftijd en persoonlijkheid. Vooral jongere kinderen gebruiken hun knuffel intensief, sleuren ermee rond en grijpen vaak kleine, uitstekende onderdelen vast. Dit benadrukt dat toekomstige ontwerpen robuust, veilig én volledig zacht moeten blijven. Ook de manier waarop kinderen knuffels vasthouden— voornamelijk aan armen, voeten of de nek—vormt een belangrijk aandachtspunt voor plaatsing van interactieve componenten.
Wat betreft de fysieke prototype-elementen werd bevestigd dat de oren de meest intuïtieve en best bereikbare locatie zijn voor de knoppen. Zowel kinderen als ouders gaven hier de voorkeur aan. Voetjes bleken bruikbaar maar minder handig, en handjes zijn problematisch omdat kinderen deze vaak vasthouden tijdens het spelen. In alle tests drukten kinderen spontaan op de knoppen op de oren, ongeacht de taak of context.
Tot slot bleek uit de situatietesten dat een scherm op de knuffel zelf niet wenselijk is: kinderen vinden het storend en het belemmert de zachtheid. Tegelijkertijd is een extern scherm moeilijk om de aandacht bij te houden. Ouders gaven aan dat een losmaakbaar scherm eventueel kan werken, maar dat een digitale en overzichtelijke oplossing zonder kwetsbare fysieke onderdelen te verkiezen is. Beide kinderen voerden de taken correct uit in zowel de scherm- als de objectversie van het prototype, al gebeurde dit iets trager in de fysieke objecttest.
In het geheel genomen levert Wave 1 duidelijke ontwerpcriteria voor de volgende fase:
– Interactieve elementen moeten zacht, robuust en veilig zijn.
– Knoppen worden best geplaatst op de oren, waar kinderen ze intuïtief vinden.
– Een harde schermintegratie kan vermeden worden; alternatieve, kindvriendelijke feedback is nodig.
Deze inzichten vormen een sterk vertrekpunt voor de verdere ontwikkeling in Wave 2.

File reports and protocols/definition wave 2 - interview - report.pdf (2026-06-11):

# Interview report Wave 2

Project informatie

Projectnaam: Planda

Dit project richt zich op het ontwikkelen van een slim product om de opvoedstress bij ouders met jonge kinderen te helpen reduceren tijdens de ochtendroutine.

Interviewer: Luna Van Tittelboom (luna.vantittelboom@ugent.be), Bram Eeckhout (bram.eeckhout@ugent.be), Doren Vermaut (doren.vermaut@ugent.be), Studenten Industrieel Ingenieur Industrieel Ontwerpen

Doelstelling en kadering

In dit project wordt gewerkt aan een slim hulpmiddel dat ouders met jonge kinderen helpt om de ochtendroutine te verlichten. Om de noden van de doelgroep beter te begrijpen, worden testinterviews afgenomen met ouders en hun jonge kinderen. Het doel van deze interviews is om inzicht te krijgen op hun huidige routine en feedback te krijgen op prototypes. Op basis van deze feedback worden verdere iteraties uitgevoerd om de gebruikservaring te optimaliseren.

Respondenten

De respondenten zijn ouders met een kind van 2 tot en met 6 jaar.

De interviews duren 45 minuten en worden afgenomen van 10/12/2025 tot 01/01/2026.

Steekproefomschrijving (N = 6)

pseudoniem | respondent type | interview datum | interview locatie
| Sofie: mama van Marit Marit: 5 jaar (Ditte: 8 jaar) | 20/12/2025 | thuis
| Kaat: mama van Claire Claire: 4 jaar (Kyrah: 9 jaar) | 21/12/2025 | thuis

Sofie & Marit (&
Ditte)

Kaat & Claire (&
Kyrah)
Emiel and lowie | 3 en 1 jaar | 18/12/2025 | thuis

Onderzoeksvragen
Op welke manieren kunnen verschillende vormen van impulsen en beloningen de aandacht en motivatie van kinderen tijdens het uitvoeren van taakjes het meest effectief beïnvloeden?
Hoe beïnvloeden de keuze van kleuren en materialen van de fysieke onderdelen van de beer het gebruiksgemak voor kinderen?

Protocol
Definition wave 2 – interview – protocol (https://drive.google.com/file/d/1jO9U5P_zEwsMB1liQGqoZsyC6XyTrukl/view?usp=sharing)

Storyboard
Het onderdeel ‘Definition’ van deze opdracht start met het maken van een storyboard. Hieruit worden enkele design challenges al direct duidelijk en is het ook duidelijk wat de context is waarin ons product gebruikt zal worden. Deze inzichten worden verder gebruikt in het maken van onze prototypes.


Prototypes
Voordat de prototypes voor de tweede wave gemaakt worden, worden er al enkele zaken mondeling besproken die we zeker willen testen. Bij het maken van de prototypes wordt er aandacht besteed aan:
1) De prototypes moeten voldoende van elkaar verschillen
2) De prototypes moeten op een zinvolle manier van elkaar verschillen


Interview analyse
Analyse uitgevoerd door Bram
Oplaadstation
Eerst werd nagegaan hoe het oplaadproces het best georganiseerd kan worden. Daarbij werd gekeken naar het afzonderlijk opladen van het scherm en de beer. Het lijkt mij niet logisch om een specifiek oplaadstation te maken als er maar 2 onderdelen opgeladen moeten worden, zeker nu dat we beslist hebben dat het scherm op de beer zit en niet in het oplaadstation. Er moet dan gewoon een duidelijke manier zijn waarop te zien is ofdat de beer of het scherm een lege batterij heeft.

Feedback
Ik heb wel opgemerkt dat een soort van beloningsysteem zeker helpt met motivatie/aandacht trekken van de kinderen. De vorm van het systeem is lastiger. Het mag niet iets zijn dat alleen op de app te zien is omdat kinderen daar geen direct zicht op hebben. Daarnaast zou het ook vervelend zijn voor de ouders om constant de app open te doen zodat de kinderen hun beloning kunnen zien (uit de test is gebleken dat ze na elk taakje hun beloning echt wel willen zien). Daarom werd tijdens de test een andere vorm van beloning gebruikt, eentje die meer te maken heeft met visuele en auditieve impulsen. Deze vorm van beloning is minder interessant als bv bamboe stokjes etc, maar heeft nog steeds een positief effect. Concreet heb ik het gedaan door de lichtjes in de oren van de beer te laten flikkeren, een groen lichtje te laten branden in de neus van de beer en ook geluidjes/muziekje deuntjes te laten afspelen.
Ik heb ook nog nagedacht over trillingen in bepaalde plaatsen zoals de handjes en pootjes, maar ik had niet echt direct de mogelijkheid om dat te doen. Ik heb geprobeerd met de gsm, maar dat was onhandig.

Aandacht trekken
Het grote probleem bij mijn vorige testen was het trekken van de aandacht van de kinderen om een taakjes te starten. Ze moeten eigenlijk uit zichzelf de beer oppakken om hun taakjes te doen. In de vorige testen werd er nog heel nauw begeleid, dit is natuurlijk niet hoe de beer in de realiteit gebruikt zal worden.
Ik heb eerst de lichtjes in de oren laten knipperen wanneer er een taakje gedaan moet worden. Dit bleek geen goed idee te zijn, de kindjes begrepen niet zo goed hoe ze de taak effectief moesten starten, pas nadat ik ingreep en hun begeleidde was het pas duidelijk. Het is dus belangrijk dat de kinderen zelf weten wanneer welke knop ingedrukt moet worden. Het is hierbij handig dat de knop die moet ingedrukt worden op dat specifieke moment alleen brandt. Op die manier trek je de aandacht van de kinderen naar die knop.

Daarnaast heb ik ook gebruikt gemaakt van geluidjes die aangeven wanneer een taakje gedaan moet worden. Deze geluidjes spelen af met kleine intervallen zodat het ook niet storend is. Op deze manier (herhalende geluidjes) wordt de aandacht goed aangetrokken. Bovendien associëren de kindjes op lange termijn (werd niet getest) die geluidjes met een taakje dat gedaan moet worden, waardoor het gemakkelijker wordt en nog minder zelf ingegrepen moet worden. Uit deze testen blijkt dat een combinatie van de twee het beste is.

Opbouw beer
Aangezien de beer die getest werd vast staat in een zittende positie, werden de plaatsing van de knoppen ook nog eens getest. Uit de eerste wave bleek dat het plaatsen van de knoppen in de pootjes geen goed idee was omdat de bodem van de poten niet altijd gemakkelijk bereikbaar zijn. Bij deze beer is dat niet het geval. Uit de test blijkt dat de oren nog steeds de beste keuze blijven, maar we moeten zeker opletten dat het materiaal van de knoppen iets taai (niet hard) en elastisch (licht vervormbaar) moet zijn omdat we niet kunnen uitsluiten dat kinderen niet in de oortjes zullen bijten (de zeer jonge kinderen). Wanneer de kinderen toch zouden bijten in de oren, bijten ze eigenlijk rechtstreeks op de hardware binnen in het oor. Om schade en verwondingen te vermijden moet het materiaal iets taais zijn.
De knoppen in de pootjes blijken nog een goede oplossing te zijn voor deze beer, maar de kinderen moeten harder knijpen in de poten omdat deze veel dikker zijn dan de oren.

Analyse uitgevoerd door Luna
Feedback
Voor dit onderdeel werden er voornamelijk vragen gesteld aan de ouders.
Uit de antwoorden van de ouders blijkt dat een beloningssysteem goed werkt om kinderen te motiveren. Wanneer een kind na een taak een beloning krijgt, is het vaak meer gemotiveerd om verder te doen. Ouders geven wel aan dat het belangrijk is dat het verzamelen van punten voor een beloning niet te lang mag duren. Als het te lang duurt kan dat juist zorgen voor minder motivatie.
Bij het nadenken over hoe een beloningssysteem in de beer verwerkt kan worden, kwam naar voren dat een visuele beloning goed zou kunnen werken. Zo kan er bijvoorbeeld op het scherm een digitale panda verschijnen die groeit of verandert wanneer een taak wordt uitgevoerd. Op die manier wordt de vooruitgang zichtbaar gemaakt, wat extra motiverend kan werken. Tegelijkertijd werd door de andere ouder aangehaald dat een fysieke beloning mogelijk beter zou werken. Hoewel het zien evolueren van een digitaal element in het begin leuk kan zijn, bestaat de kans dat dit na verloop van tijd minder interessant wordt, omdat er weinig variatie of vernieuwing in zit.
Naast een beloningssysteem met punten werd ook een ander idee besproken, namelijk dat de beer zelf feedback geeft. Deze feedback zou dan bestaan uit flikkerende lichtjes of vrolijke liedjes. Deze feedback kan helpen om kinderen aan te moedigen en hen een positief gevoel te geven na het uitvoeren van een taak.
Aandacht trekken
Om de aandacht van de kinderen te trekken, is in dit onderdeel gekeken naar hun reactie op geluiden en lichtjes (zoals in de vorige analyse). De kinderen kregen de opdracht om vrij te spelen en, zodra zij een lichtje zagen of een geluid hoorden, naar de beer te gaan en een handeling uit te voeren.
In de eerste test werden alleen lichtjes op de knoppen gebruikt. De kinderen begrepen wel dat ze op de knoppen moesten drukken, maar hadden niet altijd meteen door wanneer de taak precies begon. Hierdoor gingen ze niet direct naar de beer wanneer deze oplichtte. Dit kwam doordat ze op dat moment met iets anders bezig waren en niet naar de beer keken.
In de tweede test werd alleen geluid gebruikt. Hierbij trok de beer wel direct de aandacht van de kinderen. Echter was niet voor alle kinderen duidelijk wat er van hen verwacht werd, waardoor ze niet wisten welke handeling ze moesten uitvoeren.
In de derde test werden geluid en lichtjes gecombineerd. In deze situatie trok de beer meteen de aandacht van de kinderen en begrepen ze direct wat de bedoeling was. Door het oplichten van de knop drukten ze meteen op de juiste knop.
Deze combinatie van geluid en licht blijkt daarom de meest effectieve manier om zowel de aandacht te trekken als de juiste actie uit te lokken bij de kinderen.

Kleuren van de knoppen
Er werd een test gedaan op basis van kleuren en emoties. Hierbij moesten de kinderen de verschillende emoties plakken bij het kleur dat ze daaraan koppelen (zie definition wave 2 – interview – kleurenanalyse). (https://drive.google.com/file/d/1dnHCQTcwJ9HacUqAZoqH8H62r1BIGPhS/view?usp=sharing)
In onderstaande tabel zijn hiervan de resultaten te zien.
Kleur | Kind 1 (5 jaar) | Kind 3 (4 jaar) | Kind 2 (8 jaar) | Kind 4 (9 jaar)
Rood | Liefde, bewondering | Verdrietig, afwijzing | Boos | Boos
Oranje | Afwijzing | Boos, twijfel | Twijfelend | Blij, twijfel
Geel | Blij | Blij, super boos, bewondering | Blij, liefde | Blij, vrolijk, bewondering
Lichtgroen | Verassend | Blij | Liefde | Verdrietig
Donkergroen | Boos | Blij | Bewondering, verassend | Verbaasd
Lichtblauw | Verbaasd | Blij, verdrietig, liefde | Twijfel | Lief
Donkerblauw | Verdrietig | Verbaasd | Tegenzin | Verdrietig
Paars | Twijfelend | Verdrietig | Verbaasd, schrikken | Verbaasd
Roze | Vrolijk | Blij, liefde | Teleurstelling | Liefde

Tijdens het onderzoek is ook gekeken naar hoe deze antwoorden veranderen wanneer kinderen iets ouder zijn, om te zien of hier gelijkenissen in terug te vinden zijn. Deze antwoorden van de kinderen van 8 en 9 jaar zijn hierbij bekeken, maar worden niet meegenomen in de uiteindelijke beslissing.
Rood wordt vooral gelinkt aan negatieve gevoelens zoals verdrietig, afwijzing en boosheid, al wordt het soms ook geassocieerd met liefde. Bij oranje komt vooral twijfel naar voren. Geel en groen worden voornamelijk geassocieerd met blijheid. Donkergroen roept verschillende gevoelens op, maar deze liggen niet duidelijk op dezelfde lijn. Ook lichtblauw toont geen duidelijke overeenkomsten. Donkerblauw wordt vooral gekoppeld aan verdriet. Paars wordt gelinkt aan gevoelens zoals twijfel, verbazing en verdriet. Roze wordt daarentegen vooral positief ervaren en geassocieerd met vrolijkheid, blijheid en liefde.
Op basis van deze resultaten zou er kunnen gekozen worden voor geel als kleur voor de startknop. Geel is de enige kleur die bij de kinderen consequent een gevoel van blijheid oproept. Deze blijheid en energie sluiten goed aan bij het starten van een taak. Daarnaast zijn er geen negatieve emoties gekoppeld aan deze kleur.
Voor de knop die aangeeft dat een taak is afgerond, kan er gekozen worden voor lichtgroen. Deze kleur roept uitsluitend positieve associaties op, zoals blij en verrassend. Groen wordt bovendien vaak intuïtief geassocieerd met ‘goed’, ‘klaar’ of ‘oké’. Omdat lichtgroen rustiger is dan geel, past deze kleur goed bij het afronden van een taak.

Analyse uitgevoerd door Doren
Verderzetting van de inzichten uit Wave 1
In Wave 1 werd vastgesteld dat interactieve elementen in een knuffelbeer enkel kunnen werken wanneer de zachtheid, knuffelbaarheid en robuustheid volledig behouden blijven. Harde componenten, uitstekende onderdelen en scherminterfaces bleken problematisch, zowel op vlak van veiligheid als gebruikservaring. Daarnaast werd bevestigd dat de oren de meest intuïtieve locatie zijn voor bewuste interactie, terwijl licht een sterke, niet-intrusieve vorm van feedback vormt.
Wave 2 bouwt verder op deze conclusies en zoomt in op twee aanvullende vragen:
1. Waar mag interactie absoluut niet geplaatst worden, op basis van natuurlijk knuffelgedrag?
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

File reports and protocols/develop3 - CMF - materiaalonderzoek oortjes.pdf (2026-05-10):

CMF-onderzoek: materiaal van de oortjes
Binnen het concept van de interactieve beer functioneren de oortjes niet alleen als visueel element, maar ook als fysieke interface. Omdat de oortjes zowel indrukbaar moesten zijn als lichtfeedback moesten kunnen tonen, vormden ze een belangrijk onderdeel van het CMF-onderzoek (Color, Material, Finish). De vorm van het oor was reeds bepaald tijdens Develop 2, waar ergonomisch onderzocht werd welke vorm het best indrukbaar was en tegelijkertijd voldoende drukkracht kon overbrengen naar de interne knop. In Develop 3 verschoof de focus daarom naar materiaalkeuze, tactiliteit en afwerking.
Als eerste stap werd een volledig 3D-geprint prototype gemaakt. Dit hielp om de schaal, vorm en fysieke interactie beter te evalueren. Hoewel de vorm ergonomisch goed werkte, voelde het harde materiaal onvoldoende zacht aan voor een knuffelproduct. Hierdoor werd duidelijk dat het uiteindelijke materiaal niet alleen functioneel, maar ook emotioneel en tactiel moest aansluiten bij de rest van de beer.


Vervolgens werd een mal ontworpen om een zachter gietmateriaal te testen. Dit materiaal had een aangename textuur en voelde duidelijk zachter en kindvriendelijker aan. Tijdens het productieproces bleek echter dat het materiaal moeilijk uit de mal verwijderd kon worden zonder te scheuren of vervormen. Daarnaast sloot de kleur en afwerking minder goed aan bij de visuele uitstraling van de beer, waardoor het materiaal minder geschikt bleek binnen het bredere CMF-verhaal van het product.


Daarna werd een SLA-geprint oortje getest. Dit prototype had een zeer nauwkeurige vormgeving en was volledig transparant, waardoor het interne LED-licht zeer zichtbaar werd. Op vlak van visuele feedback werkte dit dus uitstekend. Het materiaal was echter te hard en nauwelijks indrukbaar, waardoor de knopfunctie verloren ging. Hoewel deze variant sterk scoorde op lichttransmissie en esthetiek, faalde ze op ergonomie en tactiele interactie.


Op basis van deze iteraties werd uiteindelijk gekozen voor silicone als finaal materiaal. Hiervoor werd een aparte gietmal ontworpen waarin silicone gegoten en uitgehard werd. Silicone combineerde verschillende belangrijke eigenschappen:
- het materiaal neemt nauwkeurig de gewenste vorm aan,
- het is elastisch en goed indrukbaar,
- het voelt zacht en comfortabel aan,
- en het biedt voldoende grip tijdens het knijpen.
Deze tactiele eigenschappen sluiten sterk aan bij de gewenste user experience van de beer als zacht en veilig knuffelobject. Silicone ondersteunt bovendien de affordance van het oor: kinderen begrijpen intuïtief dat het oor indrukbaar is.


Een aandachtspunt binnen deze materiaalkeuze was de beperkte lichtdoorlaatbaarheid van silicone. Hierdoor werd de zichtbaarheid van de LED-feedback verminderd. Om dit op te lossen werd een kleine opening voorzien in het oortje, waardoor het LED-licht toch duidelijk zichtbaar blijft tijdens interactie. Op deze manier bleef zowel de visuele feedback als de zachte tactiele ervaring behouden.
Dit CMF-onderzoek toont aan dat de uiteindelijke materiaalkeuze niet louter esthetisch bepaald werd, maar het resultaat is van een iteratief proces waarin ergonomie, tactiliteit, emotionele ervaring, lichtfeedback en produceerbaarheid voortdurend tegen elkaar werden afgewogen.

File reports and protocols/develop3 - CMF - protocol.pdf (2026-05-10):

# CMF protocol

Project informatie
Projectnaam: Planda
Dit project richt zich op het ontwikkelen van een slim product om de opvoedstress bij ouders met jonge kinderen te helpen reduceren. Binnen dit thema wordt onderzocht hoe technologie voor kinderen ouders helpt bij de dagelijkse uitdaging van het ouderschap.
Onderzoekers: Luna Van Tittelboom ( luna.vantittelboom@ugent.be ), Doren Vermaut ( doren.vermaut@ugent.be ), Bram Eeckhout ( bram.eeckhout@ugent.be ) Studenten Industrieel Ingenieur Industrieel Ontwerpen
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

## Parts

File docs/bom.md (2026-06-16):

## Bill of materials
Hieronder wordt een overzicht gegeven van alle onderdelen die in dit project zijn gebruikt. Enkele componenten werden in grotere hoeveelheden aangekocht of maakten deel uit van een samengesteld pakket.

<table style="width: 100%; border-collapse: collapse;">
  <thead>
    <tr style="background-color: #f2f2f2;">
      <th style="padding: 10px; text-align: center;">Categorie</th>
      <th style="padding: 10px; text-align: center;">Component</th>
      <th style="padding: 10px; text-align: center;">Aankooppagina</th>
      <th style="padding: 10px; text-align: center;">Pricing (€)</th>
    </tr>
  </thead>
  <tbody>
    <tr>
      <td rowspan="6" style="text-align: center; font-weight: bold; vertical-align: middle;">Scherm</td>
      <td style="padding: 8px; text-align: center;">ESP32-S3 N16R8</td>
      <td style="padding: 8px; text-align: center;"><a href="https://www.otronic.nl/nl/esp32-s3-n16r8-devkitc-16mb-flash-en-8mb-psram.html">OTRONIC®</a></td>
      <td style="padding: 8px; text-align: center;">19,95</td>
    </tr>
    <tr>
      <td style="padding: 8px; text-align: center;">2.8inch TFT touch screen</td>
      <td style="padding: 8px; text-align: center;"><a href="https://www.otronic.nl/nl/28inch-tft-touch-screen-320x240-ili9341-spi.html">OTRONIC®</a></td>
      <td style="padding: 8px; text-align: center;">15,05</td>
    </tr>
    <tr>
      <td style="padding: 8px; text-align: center;">Speaker 3W | 40mm | 4 Ohm</td>
      <td style="padding: 8px; text-align: center;"><a href="https://www.otronic.nl/nl/speakertje-3w-40mm.html">OTRONIC®</a></td>
      <td style="padding: 8px; text-align: center;">4,90</td>
    </tr>
    <tr>
      <td style="padding: 8px; text-align: center;">DFPlayer Mini mp3 module</td>
      <td style="padding: 8px; text-align: center;"><a href="https://www.otronic.nl/nl/dfplayer-mini-mp3-module-met-micr-140567812.html">OTRONIC®</a></td>
      <td style="padding: 8px; text-align: center;">3,49</td>
    </tr>
    <tr style="background-color: #aeedc0;">
      <td style="padding: 8px; text-align: center; background-color: #aeedc0;">Weerstand 1000 Ohm</td>
      <td style="padding: 8px; text-align: center; background-color: #aeedc0;">TIN-IN via <a href="https://www.bol.com/be/nl/p/elektronica-starter-kit/9300000072599119/">bol.com</a></td>
      <td style="padding: 8px; text-align: center; background-color: #aeedc0;">/</td>
    </tr>
    <tr style="background-color: #aeedc0;">
      <td style="padding: 8px; text-align: center; background-color: #aeedc0;">Kabels</td>
      <td style="padding: 8px; text-align: center; background-color: #aeedc0;">TIN-IN via <a href="https://www.bol.com/be/nl/p/elektronica-starter-kit/9300000072599119/">bol.com</a></td>
      <td style="padding: 8px; text-align: center; background-color: #aeedc0;">/</td>
    </tr>
    <tr>
      <td rowspan="6" style="text-align: center; font-weight: bold; vertical-align: middle;">Panda beer</td>
      <td style="padding: 8px; text-align: center;">Zittende Panda 33cm</td>
      <td style="padding: 8px; text-align: center;">Nicotoy via <a href="https://www.bol.com/be/nl/p/nicotoy-zittende-panda-33cm/9300000052332543/">bol.com</a></td>
      <td style="padding: 8px; text-align: center;">14,49</td>
    </tr>
    <tr>
      <td style="padding: 8px; text-align: center;">Magneten</td>
      <td style="padding: 8px; text-align: center;">Brute Force via <a href="https://www.bol.com/be/nl/p/brute-force-sterke-schijfmagneten-ronde-magneten-whiteboard-n35-20mm-x-2mm-5-stuks/9300000132181296/">bol.com</a></td>
      <td style="padding: 8px; text-align: center;">12,95</td>
    </tr>
    <tr style="background-color: #aeedc0;">
      <td style="padding: 8px; text-align: center; background-color: #aeedc0;">Blauwe LED (x1)<br>Groene LED (x1)<br>Orange LED (x1)</td>
      <td style="padding: 8px; text-align: center; background-color: #aeedc0;">TIN-IN via <a href="https://www.bol.com/be/nl/p/elektronica-starter-kit/9300000072599119/">bol.com</a></td>
      <td style="padding: 8px; text-align: center; background-color: #aeedc0;">/</td>
    </tr>
    <tr style="background-color: #aeedc0;">
      <td style="padding: 8px; text-align: center; background-color: #aeedc0;">Drukknoppen (x2)</td>
      <td style="padding: 8px; text-align: center; background-color: #aeedc0;">TIN-IN via <a href="https://www.bol.com/be/nl/p/elektronica-starter-kit/9300000072599119/">bol.com</a></td>
      <td style="padding: 8px; text-align: center; background-color: #aeedc0;">/</td>
    </tr>
    <tr style="background-color: #aeedc0;">
      <td style="padding: 8px; text-align: center; background-color: #aeedc0;">Weerstand 330 Ohm (x1)<br>Weerstand 220 Ohm (x2)</td>
      <td style="padding: 8px; text-align: center; background-color: #aeedc0;">TIN-IN via <a href="https://www.bol.com/be/nl/p/elektronica-starter-kit/9300000072599119/">bol.com</a></td>
      <td style="padding: 8px; text-align: center; background-color: #aeedc0;">/</td>
    </tr>
    <tr style="background-color: #aeedc0;">
      <td style="padding: 8px; text-align: center; background-color: #aeedc0;">Kabels 10cm</td>
      <td style="padding: 8px; text-align: center; background-color: #aeedc0;"><a href="https://www.otronic.nl/nl/dupont-jumper-kabels-40-stuks-male-male-10cm-draad.html">OTRONIC®</a></td>
      <td style="padding: 8px; text-align: center; background-color: #aeedc0;">1,70</td>
    </tr>
    <tr>
      <td style="padding: 8px; text-align: center; font-weight: bold;">Gedeelde componenten</td>
      <td style="padding: 8px; text-align: center;">Pogo-pin connector</td>
      <td style="padding: 8px; text-align: center;"><a href="https://nl.aliexpress.com/item/1005010576740270.html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">Aliexpress</a></td>
      <td style="padding: 8px; text-align: center;">3,75</td>
    </tr>
  </tbody>
</table>

De componenten die in het groen aangeduid zijn, werden aangekocht als onderdeel van een samengestelde set (€29,95). Dit bleek voordeliger te zijn dan de componenten afzonderlijk aan te kopen. Daarnaast wordt ervoor gekozen om een powerbank te gebruiken als voedingsbron voor het project. Deze keuze zorgt voor een eenvoudige en draagbare stroomvoorziening. Indien gewenst kan deze voedingsbron echter aangepast worden naar een andere oplossing.

Alle componenten worden aan elkaar gesoldeerd volgens volgende opstelling:
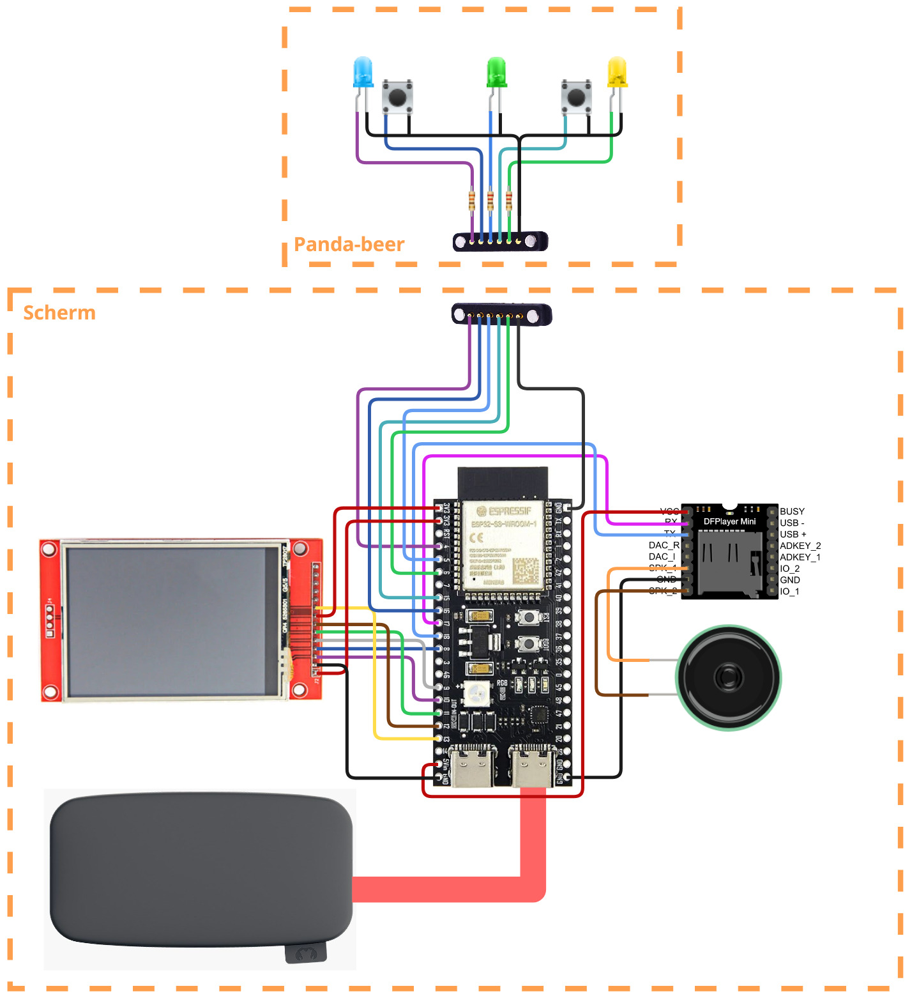
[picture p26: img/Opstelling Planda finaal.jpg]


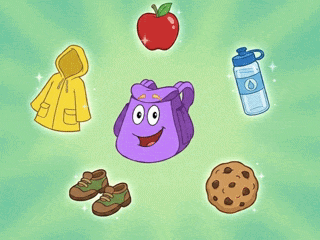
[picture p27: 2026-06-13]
planda_code/source material/Hint_3_Klaarmaken.gif

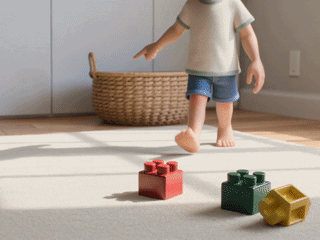
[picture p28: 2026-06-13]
planda_code/source material/Hint_1_Opruimen.gif

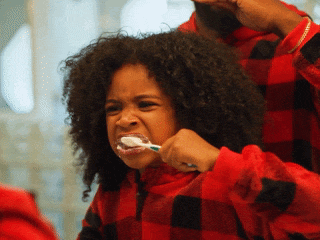
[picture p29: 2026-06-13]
planda_code/source material/Hint_2_Tandenpoetsen.gif

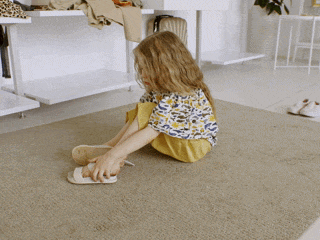
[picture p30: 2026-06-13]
planda_code/source material/Taak_3_Klaarmaken.gif

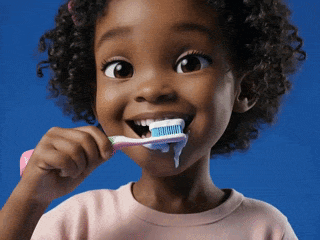
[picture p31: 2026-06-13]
planda_code/source material/Taak_2_Tandenpoetsen.gif

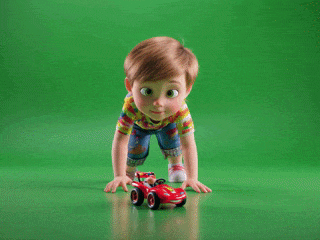
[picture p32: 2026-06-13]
planda_code/source material/Taak_1_Opruimen.gif

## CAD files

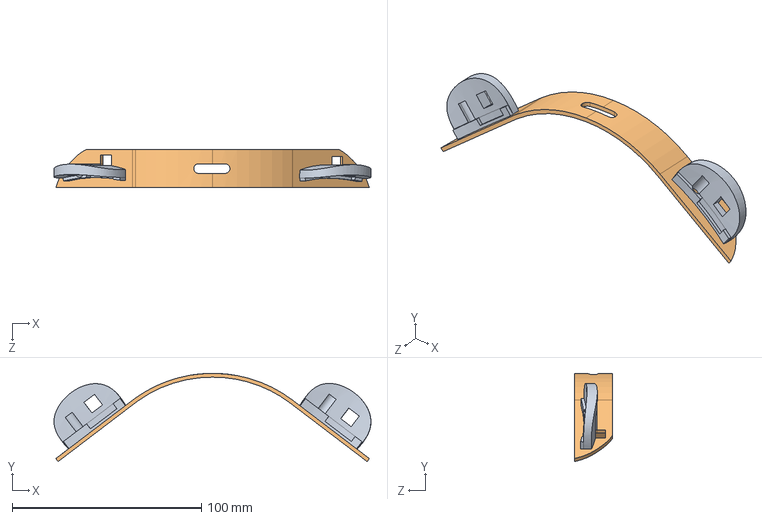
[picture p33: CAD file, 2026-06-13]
cad/260610_Oortjes_EN_Diadeem.STEP
167.3 x 46.6 x 20.0 mm

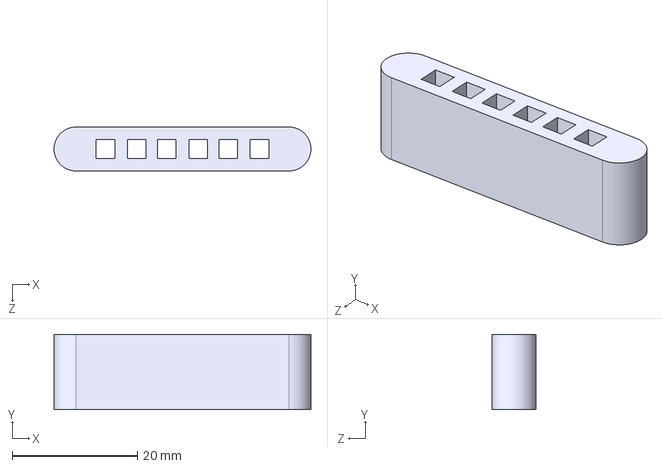
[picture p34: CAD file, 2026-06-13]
cad/260610_PogoPinConnector.STEP
41.0 x 12.0 x 7.00 mm

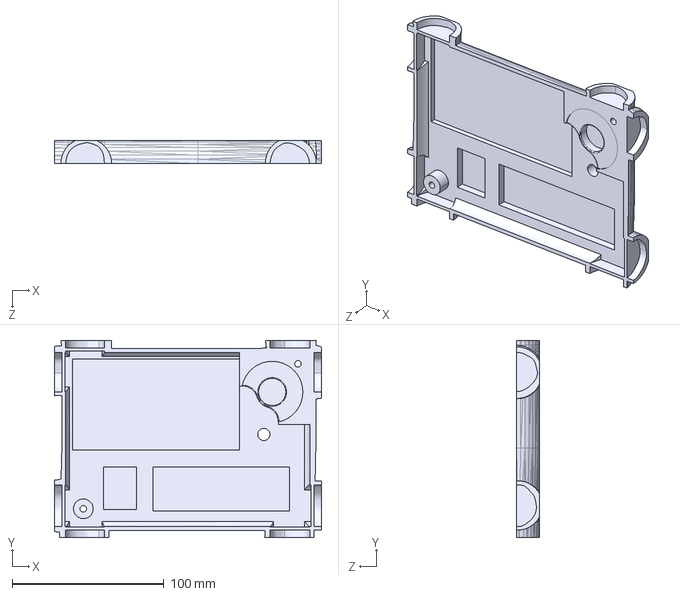
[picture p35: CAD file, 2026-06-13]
cad/260610_PGGO_Case_Onderkant.STEP
176.0 x 130.0 x 15.2 mm

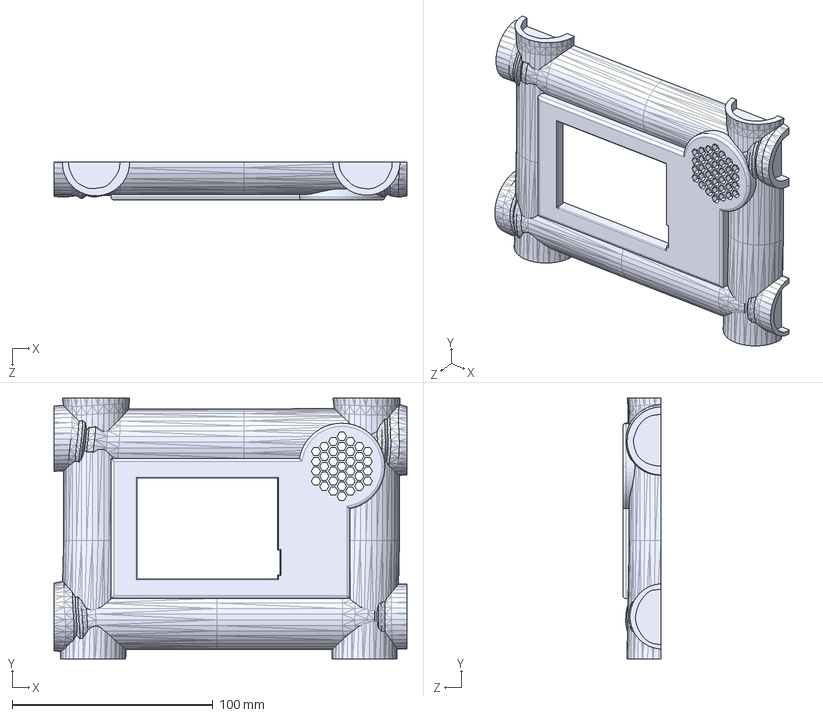
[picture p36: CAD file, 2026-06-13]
cad/260610_PGGO_Case_Bovenkant.STEP
176.0 x 130.0 x 19.0 mm

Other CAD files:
cad/bevestegingsboog.prt
cad/mal.prt
cad/oortjes eerste versie - kopie - kopie.prt

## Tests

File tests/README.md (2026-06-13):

**Test voor inputs**
Dit is code om te controleren of de ESP32 werkt.

**Test voor ouptuts**
Dit is code om te controleren of het 2.8 inch TFT display en zijn SD kaart, DFPlayer mini, knoppen en LED's werken.

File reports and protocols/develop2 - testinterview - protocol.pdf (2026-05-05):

# Testinterview protocol

Project informatie
Projectnaam: Planda
Dit project richt zich op het ontwikkelen van een slim product om de opvoedstress bij ouders met jonge kinderen te helpen reduceren. Binnen dit thema wordt onderzocht hoe technologie voor kinderen ouders helpt bij de dagelijkse uitdaging van het ouderschap.
Onderzoekers: Luna Van Tittelboom ( luna.vantittelboom@ugent.be ), Doren Vermaut ( doren.vermaut@ugent.be ), Bram Eeckhout ( bram.eeckhout@ugent.be ) Studenten Industrieel Ingenieur Industrieel Ontwerpen

Doelstelling en kadering
In dit project wordt gewerkt aan een slim hulpmiddel dat ouders met jonge kinderen helpt om de stress die optreedt tijdens de ochtendroutine te verlichten. Hierbij gaat het om een pandaknuffel met een schermpje op de buik waarop de taken visueel worden weergegeven. Daarnaast bevinden zich knoppen in de oren van de knuffel. Om deze oren ergonomisch en gebruiksvriendelijk te ontwerpen, wordt er een testinterview uitgevoerd op basis van een eerder gedane antropometrische analyse.

Onderzoeksvragen
Hoe gebruiksvriendelijk en ergonomisch zijn de oren (knoppen) voor het kindje?
- Hoe positioneert het kindje zijn/haar hand en vingers bij het bedienen van de knop?
- Is de hand- en vingerpositie consistent bij herhaald gebruik van hetzelfde oor?
- Welk oor ervaart het kindje als het meest comfortabel in de hand?
- Welk oor vindt het kindje het gemakkelijkst om te bedienen?

Discussiegids

Introductie (5 min.)
Bedankt voor je deelname aan dit onderzoek.

Ik zal starten met het project en mezelf kort voor te stellen.

Ik ben <eigen naam> en ik studeer aan de universiteit Gent campus Kortrijk met afstudeerrichting industrieel ingenieur industrieel ontwerpen.

Deze afstudeerrichting focust zich op het bedenken en verbeteren van producten. Daarom hebben we het vak Project Gebruiksgericht Ontwerpen, waarin we aan de hand van een specifiek thema een prototype moeten maken.

Het thema van dit jaar is opvoedstress. Er moet een slim product worden ontworpen voor ouders die stress ervaren bij de opvoeding van hun kind(eren) tussen de 2 en 6 jaar. Het doel van dit product is om die stress te verminderen. Samen met mijn teamgenoten werken wij aan een product voor de ochtendroutine en eventueel ook de avondroutine.

Dit testinterview is belangrijk omdat ik wil observeren hoe kinderen de knop bedienen en wil nagaan welke grootte het meest ergonomisch is.

Ik ben erg benieuwd naar uw inzichten en ervaringen. Er zijn geen juiste of foute antwoorden. Ik ben gebaat bij uw oprechte feedback rond de topics die we zullen behandelen.

Ik wil zeker nog onderstrepen dat alles wat straks in het gesprek aan bod komt in absolute confidentialiteit behandeld wordt. We zijn als studenten aan de Ugent namelijk gebonden aan de Europese privacy richtlijnen. Voor de synthese met de inzichten en aanbevelingen worden individuele meningen sowieso ook geanonimiseerd. Je naam zal met andere woorden niet gekoppeld worden aan specifieke uitspraken. Een meer gedetailleerde beschrijving van onze intenties, verwerking van gegevens, en algemeen beleid kan je nalezen in de ‘Informed Concent’. Voor we van start kunnen met het interview, heb ik jouw expliciet akkoord nodig met dit document.

Ten slotte, had ik je ook graag gevraagd of ik straks dit gesprek mag opnemen met een voice recorder, om ons gesprek te kunnen herbeluisteren wanneer de analyse wordt gemaakt. Uiteraard wordt deze opname niet gedeeld met derden, en verwijderd na afloop van het project. Als u hiermee akkoord gaat, stel ik voordat we het interview beginnen.

----------------------------[invullen informed consent & start recording] ----------------------------

Observatie (10 min.)
1. Schuif één oor op de diadeem en plaats deze op de beer.
2. Laat het kindje de knop bedienen en observeer de positie van de vinger/hand.
3. Herhaal stap 2 meerdere keren en observeer of de positie telkens op dezelfde manier wordt uitgevoerd.
4. Bevestig het andere oor op de diadeem en herhaal stap 2 en 3.
5. Bevestig het laatste oor op de diadeem en herhaal opnieuw stap 2 en 3.
Evaluatie achteraf (2 min.)
Vraag het kindje welk oor het meest comfortabel in de hand lag en het eenvoudigst te gebruiken was (en waarom).

Report
Develop2 – testinterview – report (https://drive.google.com/file/d/10HXQ8sNEB7mYRsCe3yflU_DUqUeTnOM8/view?usp=sharing)

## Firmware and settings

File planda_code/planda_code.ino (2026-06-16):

// De code voor het tonen van GIF's werd deels gebaseerd op de Youtube Tutorial: https://youtu.be/omUWkUqFYrQ
// De code voor het afspelen van audio bestanden via de DFPlayer mini werd deels gebaseerd op de Youtube Tutorial: https://www.youtube.com/watch?v=P42ICrgAtS4 
// De code voor dit project werd zo veel mogelijk zelf geschreven, AI werd gebruikt om de code te verbeteren.
// Code die door AI geschreven werd, wordt aangegeven in de lijn.


// ------ Installeren van libraries ------
#include "esp_flash.h"
#include "esp_partition.h"
#include <bb_spi_lcd.h>
#include <AnimatedGIF.h>
#include "DFRobotDFPlayerMini.h"


// ------ GIF bestanden ------
// --- Taakjes ---
#include "gif_files/Taak_1_Opruimen.h"
#include "gif_files/Taak_2_Tandenpoetsen.h"
#include "gif_files/Taak_3_Klaarmaken.h"
#define GifData Taak_1_Opruimen
#define GifData Taak_2_Tandenpoetsen
#define GifData Taak_3_Klaarmaken

// --- Hints ---
#include "gif_files/Hint_1_Opruimen.h"
#include "gif_files/Hint_2_Tandenpoetsen.h"
#include "gif_files/Hint_3_Klaarmaken.h"
#define GifData Hint_1_Opruimen
#define GifData Hint_2_Tandenpoetsen
#define GifData Hint_3_Klaarmaken


// ------ Definieer pinnen -------
// --- 2.8 Inch TFT Display ---
#define TFT_CS    10
#define TFT_DC    9
#define TFT_RST   8
#define TFT_LED   21
#define TFT_MISO  13
#define TFT_MOSI  11
#define TFT_CLK   12

// --- DFPlayer Mini ---
#define DF_RX 16 // verbind met TX van de DFPlayer mini
#define DF_TX 17 // verbind met RX van de DFPlayer mini (+ 1k weerstand als VCC aangesloten is op 5V)

// --- Drukknoppen ---
#define Blauwe_knop 15
#define Orange_knop 5

// --- LED's ---
#define Blauwe_led 4
#define Orange_led 7
#define Groene_led 6


// ------ Definieer variabelen -------
// --- Objecten ---
BB_SPI_LCD tft;
DFRobotDFPlayerMini myDFPlayer;
AnimatedGIF gif;

// --- Status managment ---
// [!] Deze code werd gegenereerd door AI (gemini)
int Huidige_taak = 0;
bool Wordt_actie_getoond = false; // Zijn we momenteel de actie-afbeelding aan het tonen?
bool Taak_gedaan = false;
unsigned long Audio_Timer_Start = 0;
bool Wacht_Op_Muziek = false;
unsigned long Taak_Audio_Timer_Start = 0;
bool Wacht_Op_Taak_Audio = false;
int Geplande_Taak_Index = 0;

// --- GIF data voor de taakjes ---
#define GIF_COUNT 3
const uint8_t* taakgifData[GIF_COUNT] = {Taak_1_Opruimen, Taak_2_Tandenpoetsen, Taak_3_Klaarmaken};
const size_t taakgifSizes[GIF_COUNT] = {sizeof(Taak_1_Opruimen), sizeof(Taak_2_Tandenpoetsen), sizeof(Taak_3_Klaarmaken)};

// --- GIF data voor de hints ---
const uint8_t* hintgifData[GIF_COUNT] = {Hint_1_Opruimen, Hint_2_Tandenpoetsen, Hint_3_Klaarmaken};
const size_t hintgifSizes[GIF_COUNT] = {sizeof(Hint_1_Opruimen), sizeof(Hint_2_Tandenpoetsen), sizeof(Hint_3_Klaarmaken)};

// --- Debounce variabelen ---
// [!] Deze code werd gegenereerd door AI (gemini)
int lastNextState = -1, nextState = -1;
unsigned long lastNextDebounce = 0;
int lastActionState = -1, actionState = -1;
unsigned long lastActionDebounce = 0;

// --- LED timers en status ---
unsigned long Knipper_Blauw_Start = 0;
unsigned long Knipper_Orange_Start = 0;
unsigned long Groen_Start = 0;
bool Knipper_Blauw_On = false;
bool Knipper_Orange_On = false;
bool Groen_On = false;

// --- Reset timer ---
unsigned long Knoppen_Samen_Ingedrukt_Start = 0;

// ------ Start Code ------
void setup() {
  Serial.begin(115200);
  Serial2.begin(9600, SERIAL_8N1, DF_RX, DF_TX);
  
  if (!myDFPlayer.begin(Serial2)) { // kleine status controle. Ik merk op dat de dfplayer op 3.3V niet altijd werkt. Kan opgelost worden door serial monitor eens aan/uit te doen.
    Serial.println("DFPlayer error: Check verbinding en SD-kaart!");
  } else {
    Serial.println("DFPlayer online!");
  }
  myDFPlayer.volume(25); // volume gaat van 0 t.e.m. 30

  if (psramInit()) { // we werken niet met de SD kaartlezer op het TFT scherm. We werken met het PSRAM (8Mb) van de ESP32. Dit is een kleine statuscontrole.
    Serial.println("PSRAM succesvol geïnitialiseerd!");
  } else {
    Serial.println("PSRAM niet gevonden!");
  }
  
  pinMode(Blauwe_knop, INPUT_PULLUP);
  pinMode(Orange_knop, INPUT_PULLUP);
  
  pinMode(Blauwe_led, OUTPUT);
  pinMode(Orange_led, OUTPUT);
  pinMode(Groene_led, OUTPUT);
  digitalWrite(Blauwe_led, HIGH);
  digitalWrite(Orange_led, HIGH);
  digitalWrite(Groene_led, LOW);

  pinMode(TFT_LED, OUTPUT);
  digitalWrite(TFT_LED, HIGH);
  
  tft.begin(LCD_ILI9341, FLAGS_NONE, 40000000, TFT_CS, TFT_DC, TFT_RST, TFT_LED, TFT_MISO, TFT_MOSI, TFT_CLK);
  tft.setRotation(LCD_ORIENTATION_90);
  tft.fillScreen(TFT_BLACK);

  loadtaakGif(Huidige_taak); // Dit toont de eerste taak op het scherm
  delay(200);
  yield();
  myDFPlayer.play(Huidige_taak + 5);
  Wacht_Op_Taak_Audio = false;
}

void loop() {
  unsigned long nu = millis();

  // --- RESET LOGICA: Beide knoppen 5 seconden ingedrukt houden ---
  // Omdat INPUT_PULLUP is gebruikt, is een knop ingedrukt als de status LOW is.
  if (digitalRead(Blauwe_knop) == LOW && digitalRead(Orange_knop) == LOW) {
    if (Knoppen_Samen_Ingedrukt_Start == 0) {
      Knoppen_Samen_Ingedrukt_Start = nu;
      Serial.println("Beide knoppen ingedrukt... Timer gestart.");
    } else if (nu - Knoppen_Samen_Ingedrukt_Start >= 5000) {
      Serial.println("SYSTEM RESET: Terug naar taak 1!");

      // 1. Reset alle status variabelen
      Huidige_taak = 0;
      Wordt_actie_getoond = false;
      Taak_gedaan = false;
      Wacht_Op_Muziek = false;

      // 2. Reset alle LED timers en zet LEDs in beginstand
      Knipper_Blauw_On = false;
      Knipper_Orange_On = false;
      Groen_On = false;
      digitalWrite(Blauwe_led, HIGH);
      digitalWrite(Orange_led, HIGH);
      digitalWrite(Groene_led, LOW);

      // 3. Maak scherm leeg en laad de eerste taak opnieuw
      tft.fillScreen(TFT_BLACK);
      loadtaakGif(Huidige_taak);

      // Reset de timer zodat we niet in een oneindige reset-loop blijven hangen
      Knoppen_Samen_Ingedrukt_Start = 0;
      
      delay(1000); 
      return; 
    }
  } else {
    // Zodra één van de twee knoppen (of allebei) wordt losgelaten, resetten we de timer
    Knoppen_Samen_Ingedrukt_Start = 0;
  }
  
  // --- Optie 1: Ga door naar de volgende taak (blauwe knop + blauwe LED knipperen + groene LED) ---
  if (isButtonPressed(Blauwe_knop, nextState, lastNextState, lastNextDebounce)) { // [!] Deze code werd gegenereerd door AI (gemini)
    Huidige_taak++;                                                               // |||||||||||||||||||||||||||||||||||||||||||||||
    Wordt_actie_getoond = false;                                                  // |||||||||||||||||||||||||||||||||||||||||||||||
    Wacht_Op_Muziek = false;
    
    myDFPlayer.play(1); // speelt geluidje dat taak gedaan is
    
    Knipper_Blauw_On = true;
    Knipper_Blauw_Start = nu;
    Groen_On = true;
    Groen_Start = nu;
    digitalWrite(Groene_led, HIGH);

    if (Huidige_taak < GIF_COUNT) { // zorgt voor opvolging van taak 1 naar 3. Zal na de derde taak een zwart scherm geven.
      Serial.printf("Naar taak %d\n", Huidige_taak + 1); // [!] Deze code werd gegenereerd door AI (gemini)
      tft.fillScreen(TFT_BLACK);
      loadtaakGif(Huidige_taak);
      Geplande_Taak_Index = Huidige_taak;
      Taak_Audio_Timer_Start = nu;
      Wacht_Op_Taak_Audio = true;
    } else {
      Serial.println("Taak is gedaan");
      tft.fillScreen(TFT_BLACK);
      Taak_gedaan = true;
    }
    return;
  }

  // --- Optie 2: Geef extra instructies (oranje knop + oranje LED) ---
  if (!Taak_gedaan && isButtonPressed(Orange_knop, actionState, lastActionState, lastActionDebounce)) { // [!] Deze code werd gegenereerd door AI (gemini)
    if (!Wordt_actie_getoond) {                                                                         // |||||||||||||||||||||||||||||||||||||||||||||||
      Serial.println("Kindje wil extra hulp");                                                          // |||||||||||||||||||||||||||||||||||||||||||||||
      Wordt_actie_getoond = true;                                                                       // |||||||||||||||||||||||||||||||||||||||||||||||
      
      Knipper_Orange_On = true;
      Knipper_Orange_Start = nu;
      
      myDFPlayer.play(Huidige_taak + 8);
      Audio_Timer_Start = nu;
      Wacht_Op_Muziek = true;

      tft.fillScreen(TFT_BLACK); // altijd bij het switchen van gifs eerst kort een zwart scherm toevoegen, dat helpt bij het renderen.
      loadhintGif(Huidige_taak);
      return;
    }
  }

// Audio-sync
if (Wacht_Op_Muziek) {
    if (nu - Audio_Timer_Start >= 9000) {
      myDFPlayer.play(Huidige_taak + 2);
      Wacht_Op_Muziek = false;
      Serial.println("AI-stem klaar, muziek gestart.");
    }
  }
if (Wacht_Op_Taak_Audio) {
    if (nu - Taak_Audio_Timer_Start >= 9000) {
      myDFPlayer.play(Geplande_Taak_Index + 5);
      Wacht_Op_Taak_Audio = false;
      Serial.println("Succes-geluid klaar, nieuwe taak-audio gestart.");
    }
  }

// --- LED timers en status updates ---
if (Knipper_Blauw_On) {
    if (nu - Knipper_Blauw_Start < 3000) {
      if ((nu / 200) % 2 == 0) digitalWrite(Blauwe_led, HIGH);
      else digitalWrite(Blauwe_led, LOW);
    } else {
      Knipper_Blauw_On = false;
      digitalWrite(Blauwe_led, HIGH);
    }
  }

if (Knipper_Orange_On) {
    if (nu - Knipper_Orange_Start < 3000) {
      if ((nu / 200) % 2 == 0) digitalWrite(Orange_led, HIGH);
      else digitalWrite(Orange_led, LOW);
    } else {
      Knipper_Orange_On = false;
      digitalWrite(Orange_led, HIGH);
    }
  }

  if (Groen_On) {
    if (nu - Groen_Start >= 2000) {
      Groen_On = false;
      digitalWrite(Groene_led, LOW);
    }
  }

  // --- Rendering ---
  if (!Taak_gedaan) {
    if (gif.getCanvasWidth() > 0) {
      gif.playFrame(false, NULL);
    }
  }
}


// ------ Functie om een nieuwe taak GIF klaar te zetten ------
void loadtaakGif(int index) {                                                   // [!] Deze code werd gegenereerd door AI (gemini)
  Serial.println("Vrijmaken geheugen...");
  gif.close();
  gif.freeFrameBuf(GIFFree);
  delay(100); 
  yield();
  Serial.printf("PSRAM vrij voor start: %d bytes\n", ESP.getFreePsram());       // [!] Deze code werd gegenereerd door AI (gemini)
  gif.begin(GIF_PALETTE_RGB565_BE);                                             // |||||||||||||||||||||||||||||||||||||||||||||||
  if (gif.open((uint8_t *)taakgifData[index], taakgifSizes[index], GIFDraw)) {  // |||||||||||||||||||||||||||||||||||||||||||||||
    gif.setDrawType(GIF_DRAW_COOKED);                                           // |||||||||||||||||||||||||||||||||||||||||||||||
    if (gif.allocFrameBuf(GIFAlloc) != GIF_SUCCESS) {                           // |||||||||||||||||||||||||||||||||||||||||||||||
      Serial.println("PSRAM Allocatie mislukt!");                               // |||||||||||||||||||||||||||||||||||||||||||||||
    } else {                                                                    // |||||||||||||||||||||||||||||||||||||||||||||||
      Serial.println("Taak GIF geladen!");                                      // |||||||||||||||||||||||||||||||||||||||||||||||
    }
  }
}

// ------ Functie om een nieuwe hint GIF klaar te zetten ------
void loadhintGif(int index) {                                                   // [!] Deze code werd gegenereerd door AI (gemini)
  Serial.println("Vrijmaken geheugen...");
  gif.close();
  gif.freeFrameBuf(GIFFree);
  delay(100); 
  yield();
  Serial.printf("PSRAM vrij voor start: %d bytes\n", ESP.getFreePsram());       // [!] Deze code werd gegenereerd door AI (gemini)
  gif.begin(GIF_PALETTE_RGB565_BE);                                             // |||||||||||||||||||||||||||||||||||||||||||||||
  if (gif.open((uint8_t *)hintgifData[index], hintgifSizes[index], GIFDraw)) {  // |||||||||||||||||||||||||||||||||||||||||||||||
    gif.setDrawType(GIF_DRAW_COOKED);                                           // |||||||||||||||||||||||||||||||||||||||||||||||
    if (gif.allocFrameBuf(GIFAlloc) != GIF_SUCCESS) {                           // |||||||||||||||||||||||||||||||||||||||||||||||
      Serial.println("PSRAM Allocatie mislukt!");                               // |||||||||||||||||||||||||||||||||||||||||||||||
    } else {                                                                    // |||||||||||||||||||||||||||||||||||||||||||||||
      Serial.println("Hint GIF geladen!");                                      // |||||||||||||||||||||||||||||||||||||||||||||||
    }
  }
}

// ------ knop-checker ------
// [!] Deze code werd gegenereerd door AI (gemini)
bool isButtonPressed(int pin, int &state, int &lastState, unsigned long &lastDebounce) {
  int reading = digitalRead(pin);
  if (reading != lastState) lastDebounce = millis();
  if ((millis() - lastDebounce) > 50) {
    if (reading != state) {
      state = reading;
      return state == LOW;
    }
  }
  lastState = reading;
  return false;
}


// ------ GIF helper functies (Nodig voor bb_spi_lcd) ------
void *GIFAlloc(uint32_t u32Size) { return heap_caps_malloc(u32Size, MALLOC_CAP_SPIRAM); } // [!] Deze code werd gegenereerd door AI (gemini)
void GIFFree(void *p) { heap_caps_free(p); }                                              // |||||||||||||||||||||||||||||||||||||||||||||||                

// Dit is de manier van de gif tekenen. Deels gevolgd uit de tutorial, ook AI.
void GIFDraw(GIFDRAW *pDraw) {
  if (pDraw->iY + pDraw->y >= tft.height() || pDraw->iX >= tft.width()) return;
  tft.pushImage(
    pDraw->iX,
    pDraw->iY + pDraw->y,
    pDraw->iWidth,
    1,
    (uint16_t *)pDraw->pPixels
  );
}

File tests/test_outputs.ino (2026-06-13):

// Dit is code om te controleren of het 2.8 inch TFT display en zijn SD kaart, DFPlayer mini, knoppen en LED's werken.
// Opmerking! Het kan zijn dat na het uploaden de RST knop kort ingedrukt moet worden als er niets wordt terug gegeven via de serial monitor.
// Er zal telkens vermeld worden bij de code lines wanneer er AI gebruikt werd.


// ------ Installeer de nodige libraries ------

#include <SPI.h>
#include <SD.h>
#include <Adafruit_GFX.h>
#include <Adafruit_ILI9341.h>


// ------ Configureer de nodige componenten ------

// ipv het bestandje TFT_eSPI.h aan te passen, schrijf ik het liever voluit. Dit zal ik niet doen bij het schrijven van d ehoofdcode, maar direct integreren in een functie.
// Op deze manier heb ik al meerdere malen mezelf gevangen op het verkeerd verbinden van de poorten
// bekijk https://randomnerdtutorials.com/esp32-s3-devkitc-pinout-guide/ om de juiste pins te gebruiken!

#define TFT_CS   10
#define TFT_DC   9
#define TFT_RST  8
#define SPI_MOSI 11
#define SPI_MISO 13
#define SPI_SCK  12

Adafruit_ILI9341 tft = Adafruit_ILI9341(TFT_CS, TFT_DC, TFT_RST); // De initialisatie werd geschreven door AI, in de hoofdcode heb ik op een andere manier gewerkt

const int button1Pin = 4;
const int button2Pin = 5;
const int ledBlauwPin = 6;
const int ledGroenPin = 7;
const int ledGeelPin = 15;


// ----- Test of het display werkt ------

void setup() { // Visuele controle van de werking van het scherm door het scherm groen te maken.
  Serial.begin(115200);
  while (!Serial) {
    delay(10); 
  }
  
  Serial.println("\n Start Test!"); // Dit wordt gedaan omdat ik naast visuele feedback ook feedback wil via de serial monitor
  Serial2.begin(9600, SERIAL_8N1, 16, 17);
  
  if (!myDFPlayer.begin(Serial2)) {
    Serial.println("DFPlayer error: Check verbinding en SD-kaart!");
  } else {
    Serial.println("DFPlayer online!");
  }
  myDFPlayer.volume(20);

   wil krijgen via de Serialmonitor => dan weet ik op welke plaats in de code ik moet kijken.

  SPI.begin(SPI_SCK, SPI_MISO, SPI_MOSI); // Initialiseer SPI (Werd door AI als aparte stap gedaan, los van Adafruit_ILI9341 tft = ...

  tft.begin();
  tft.setRotation(1);
  tft.fillScreen(ILI9341_GREEN); // Of gebruik een kleurcode
  Serial.println("Display: Scherm is nu GROEN.");
  tft.setTextColor(ILI9341_BLACK);
  tft.setTextSize(2);
  tft.setCursor(50, 100);
  tft.println("Scherm werkt!");
  
  Serial.println("Test Klaar!");
}


void loop() { // In principe niet nodig, heb deze nu toegevoegd omdat ik soms de melding kreeg dat de ESP32 connect en disconnect. Soms wordt dit opgelost door kort op de RST knop te duwen op het bordje.
              // Op deze manier weet ik dat de controller niet meer werkt als er niets meer geprint wordt.
  Serial.println("Systeem is actief...");
  delay(5000); 
}


// ----- Test of de drukknoppen en de lampjes werken -----

void setup() { // Deze code is gelijkaardig aan oefening 1.4.1
  Serial.begin(115200);
  
  pinMode(buttonPin1, INPUT_PULLUP);
  pinMode(ledBlauwPin, OUTPUT);
  digitalWrite(ledBlauwPin, LOW);

  pinMode(buttonPin2, INPUT_PULLUP);
  pinMode(ledGeelPin, OUTPUT);
  digitalWrite(ledGeelPin, LOW);

  pinMode(ledGroenPin, OUTPUT);
  digitalWrite (ledGroenPin, HIGH);
}

void loop() {
  digitalWrite(ledBlauwPin, digitalRead(button1Pin));
  digitalWrite(ledGeelPin, digitalRead(button2Pin));

  if (digitalRead(buttonPin1) == LOW) {
    Serial.println("De rechter knop is ingedrukt dus de Blauwe LED gaat uit");
  }
  if (digitalRead(buttonPin2) == LOW) {
    Serial.println("De linker knop is ingedrukt dus de gele LED gaat uit");
  }
}

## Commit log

2026-03-03 Aanpassingen in BOM
2026-03-03 aanpassingen BOM (2)
2026-03-03 foutje in BOM, wil niet weergeven op github
2026-03-03 2de poging BOM
2026-03-03 BOM (3de keer)
2026-03-03 BOM aangepast
2026-03-03 aanpassing BOM
2026-03-03 verwijder BOM
2026-03-03 BOM (laatste keer)
2026-03-08 aanvullen des req
2026-04-21 Vorm en materiaal van de oortjes
2026-05-05 CAD files toegevoegd
2026-05-05 alle Cad files + render foto's
2026-05-05 beschrijving van Cad
2026-05-10 CAD layout aanpassen en fotos verplaatsen
2026-06-10 technische omgeschrijving bij BOM
2026-06-13 Aanvullende tekst voor de Definition‑fase
2026-06-13 test cad
    [bevestegingsboog.prt]
2026-06-13 aanvullen cad bestanden
    [mal.prt, oortjes eerste versie - kopie - kopie.prt]
2026-06-13 CAD bestanden
    [260610_Oortjes_EN_Diadeem.STEP, 260610_PGGO_Case_Bovenkant.STEP, 260610_PGGO_Case_Onderkant.STEP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]
2026-06-13 bestanden arduino
